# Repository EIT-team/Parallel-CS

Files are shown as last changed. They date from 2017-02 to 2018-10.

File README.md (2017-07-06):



# Parallel-CS
Parallel inject current source schematic and programming code, using AD9833 DDS IC.

Includes: Circuit schematics, PCB Layout, Arduino code for programming output frequency and/or phase of CS.

**Instructions for programming CS board**

- Turn on power (Press both push button switches).
- Connect mini-USB cable to Arduino.
- Open /src/DDS_PCB/DDS_PCB.ino and upload to Arduino.

Devices will be initially be programmed to default frequencies, specified in the src/frequencies.h file.

After programming, frequency and/or phase can be adjusted using serial monitor:
- Open serial monitor (Ctrl-Shift-M)
- Make sure line ending is set to '_no line ending_' and baud rate is 9600
- '_freq chan value_' will set the frequency of _chan_ to _value_ e.g. '_freq 2 2500_' sets channel 2 to 2500Hz
- '_phase chan value_' will set the phase in degrees of _chan_ to _value_ e.g. '_phase 2 50_' sets phase of channel 2 to 50 degrees. Phase is 0 by default.
- The terminal should echo a message confirming programming is happening.

Once programmed, the USB cable can be unplugged.

board

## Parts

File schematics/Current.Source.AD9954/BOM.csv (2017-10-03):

Qty | Value | Device | Package | Parts | Description | MF | MPN | OC_FARNELL | OC_NEWARK | PACKAGE | SUPPLIER | TP_SIGNAL_NAME
1 |  | JP3Q | JP3Q | JP1 | JUMPER
2 |  | M02-JST-2MM-SMT | JST-2-SMD | JP2, JP3 | Header 2
19 | 0.1uF | C-EUC0603 | C0603 | C1, C2, C4, C6, C7, C8, C9, C10, C11, C12, C13, C23, C25, C27, C29, C30, C31, C36, C38 | CAPACITOR, European symbol
4 | 100K | R-US_R0805 | R0805 | R1_0.1%, R2_0.1%, R6_0.1%, R7_0.1% | RESISTOR, American symbol
2 | 10k | R-US_R0805 | R0805 | R3, R_GAIN3_0.1% | RESISTOR, American symbol
17 | 10uF | C-EUC0603 | C0603 | C3, C5, C15, C16, C17, C18, C19, C20, C21, C24, C26, C28, C32, C33, C34, C35, C37 | CAPACITOR, European symbol
1 | 1150 | R-US_R0805 | R0805 | R4_DAC_1% | RESISTOR, American symbol
2 | 1500 | R-US_R0805 | R0805 | R2_DAC_1%, RG_DAC_1% | RESISTOR, American symbol
1 | 287 | R-US_R0805 | R0805 | RX_DAC_1% | RESISTOR, American symbol
1 | 2k | R-US_R0805 | R0805 | R_GAIN1_0.1% | RESISTOR, American symbol
1 | 309 | R-US_R0805 | R0805 | RY_DAC_1% | RESISTOR, American symbol
1 | 5k | R-US_R0805 | R0805 | R_GAIN2_0.1% | RESISTOR, American symbol
1 | 7.838k | R-US_R0805 | R0805 | R_SET1_0.1% | RESISTOR, American symbol
2 | 750 | R-US_R0805 | R0805 | R3_DAC_1%, RF_DAC_1% | RESISTOR, American symbol
1 | 931 | R-US_R0805 | R0805 | R1_DAC_1% | RESISTOR, American symbol
1 | AD9954YSVZ | AD9954YSVZ | QFP50P900X900X120-49N | U1 | Direct Digital Synthesizer |  | AD9954YSVZ | 1581969 | 19M8953 | TQFP-48 | ANALOG DEVICES
1 | ARDUINO_DUE | ARDUINO_DUE | ARDUINO_DUE | PCB1 | Device for representing an Arduino Due board with a footprint in an EAGLE design. Created by Dave Young for Element14. More EAGLE documentation at: http://www.element14.com/community/community/knode/cadsoft_eagle
1 | LTC1044CS8PBF | LTC1044CS8PBF | SOIC127P600X175-8N | U4 | Switched Capacitor Voltage Converter |  | LTC1044CS8#PBF | 1663593 | 55M8900 | SOIC-8 | Linear Technology
1 | LTC69000 | LTC69000 | SOT23-5L | U2 | Low Power, 1kHz to 20MHz
13 | PTR1PAD1-13 | PTR1PAD1-13 | P1-13 | 1.8VA, 1.8VD, 3V3, CLK, GND, IOUT+, IOUT-, SCLK, SDIO, SDO, TP5, VIN_NEG, VIN_POS | TEST PIN
1 | RC4560S08-RC4560 | RC4560S08-RC4560 | SO8 | OP1 | RC4560 Op-Amp
2 | REG1117 | REG1117 | SOT223 | IC1, IC2 | 800mA and 1A Low Dropout (LDO) Positive Regulator |  | REG1117 | 1097566 | 14P6981
1 | TL42PO | TL42PO | TL4XPO | S3 | TINY SWITCH ON - MOM

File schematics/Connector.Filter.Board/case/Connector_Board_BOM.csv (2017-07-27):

Part | Value | Device | Package | Description | BTM_NEG | BTM_POS | MF | MPN | OC_FARNELL | OC_NEWARK | PROD_ID | TOP_NEG | TOP_POS | TP_SIGNAL_NAME
C1 | 0.1uF | C-EUC0402 | C0402 | CAPACITOR, European symbol
C2 | 0.1uF | C-EUC0402 | C0402 | CAPACITOR, European symbol
C3 | 0.1uF | C-EUC0402 | C0402 | CAPACITOR, European symbol
C4 | 0.1uF | C-EUC0402 | C0402 | CAPACITOR, European symbol
C5 | 0.1uF | C-EUC0402 | C0402 | CAPACITOR, European symbol
C6 | 0.1uF | C-EUC0402 | C0402 | CAPACITOR, European symbol
C7 | 0.1uF | C-EUC0402 | C0402 | CAPACITOR, European symbol
C8 | 0.1uF | C-EUC0402 | C0402 | CAPACITOR, European symbol
C9 | 0.1uF | C-EUC0402 | C0402 | CAPACITOR, European symbol
C10 | 0.1uF | C-EUC0402 | C0402 | CAPACITOR, European symbol
C11 | 0.1uF | C-EUC0402 | C0402 | CAPACITOR, European symbol
C12 | 0.1uF | C-EUC0402 | C0402 | CAPACITOR, European symbol
C13 | 0.1uF | C-EUC0402 | C0402 | CAPACITOR, European symbol
C14 | 0.1uF | C-EUC0402 | C0402 | CAPACITOR, European symbol
C15 | 0.1uF | C-EUC0402 | C0402 | CAPACITOR, European symbol
C16 | 0.1uF | C-EUC0402 | C0402 | CAPACITOR, European symbol
C17 | 0.1uF | C-EUC0402 | C0402 | CAPACITOR, European symbol
C18 | 0.1uF | C-EUC0402 | C0402 | CAPACITOR, European symbol
C19 | 1uf | C-EUC0805 | C0805 | CAPACITOR, European symbol
C20 | 1uf | C-EUC0805 | C0805 | CAPACITOR, European symbol
C21 | 1uf | C-EUC0805 | C0805 | CAPACITOR, European symbol
C22 | 1uf | C-EUC0805 | C0805 | CAPACITOR, European symbol
C23 | 1uf | C-EUC0805 | C0805 | CAPACITOR, European symbol
C24 | 1uf | C-EUC0805 | C0805 | CAPACITOR, European symbol
C25 | 1uf | C-EUC0805 | C0805 | CAPACITOR, European symbol
C26 | 1uf | C-EUC0805 | C0805 | CAPACITOR, European symbol
C27 | 1uf | C-EUC0805 | C0805 | CAPACITOR, European symbol
C28 | 1uf | C-EUC0805 | C0805 | CAPACITOR, European symbol
C29 | 1uf | C-EUC0805 | C0805 | CAPACITOR, European symbol
C30 | 1uf | C-EUC0805 | C0805 | CAPACITOR, European symbol
C31 | 0.1uF | C-EUC0402 | C0402 | CAPACITOR, European symbol
C32 | 0.1uF | C-EUC0402 | C0402 | CAPACITOR, European symbol
C33 | 0.1uF | C-EUC0402 | C0402 | CAPACITOR, European symbol
C34 | 0.1uF | C-EUC0402 | C0402 | CAPACITOR, European symbol
C35 | 0.1uF | C-EUC0402 | C0402 | CAPACITOR, European symbol
C36 | 0.1uF | C-EUC0402 | C0402 | CAPACITOR, European symbol
C37 | 0.1uF | C-EUC0402 | C0402 | CAPACITOR, European symbol
C38 | 0.1uF | C-EUC0402 | C0402 | CAPACITOR, European symbol
C39 | 0.1uF | C-EUC0402 | C0402 | CAPACITOR, European symbol
C40 | 0.1uF | C-EUC0402 | C0402 | CAPACITOR, European symbol
C41 | 0.1uF | C-EUC0402 | C0402 | CAPACITOR, European symbol
C42 | 0.1uF | C-EUC0402 | C0402 | CAPACITOR, European symbol
C43 | 0.1uF | C-EUC0402 | C0402 | CAPACITOR, European symbol
C44 | 0.1uF | C-EUC0402 | C0402 | CAPACITOR, European symbol
C45 | 0.1uF | C-EUC0402 | C0402 | CAPACITOR, European symbol
C46 | 0.1uF | C-EUC0402 | C0402 | CAPACITOR, European symbol
C47 | 0.1uF | C-EUC0402 | C0402 | CAPACITOR, European symbol
C48 | 0.1uF | C-EUC0402 | C0402 | CAPACITOR, European symbol
C49 | 1uf | C-EUC0805 | C0805 | CAPACITOR, European symbol
C50 | 1uf | C-EUC0805 | C0805 | CAPACITOR, European symbol
C51 | 1uf | C-EUC0805 | C0805 | CAPACITOR, European symbol
C52 | 1uf | C-EUC0805 | C0805 | CAPACITOR, European symbol
C53 | 1uf | C-EUC0805 | C0805 | CAPACITOR, European symbol
C54 | 1uf | C-EUC0805 | C0805 | CAPACITOR, European symbol
C55 | 1uf | C-EUC0805 | C0805 | CAPACITOR, European symbol
C56 | 1uf | C-EUC0805 | C0805 | CAPACITOR, European symbol
C57 | 1uf | C-EUC0805 | C0805 | CAPACITOR, European symbol
C58 | 1uf | C-EUC0805 | C0805 | CAPACITOR, European symbol
C59 | 1uf | C-EUC0805 | C0805 | CAPACITOR, European symbol
C60 | 1uf | C-EUC0805 | C0805 | CAPACITOR, European symbol
C61 | 0.1uF | C-EUC0402 | C0402 | CAPACITOR, European symbol
C62 | 0.1uF | C-EUC0402 | C0402 | CAPACITOR, European symbol
C63 | 0.1uF | C-EUC0402 | C0402 | CAPACITOR, European symbol
C64 | 0.1uF | C-EUC0402 | C0402 | CAPACITOR, European symbol
C65 | 0.1uF | C-EUC0402 | C0402 | CAPACITOR, European symbol
C66 | 0.1uF | C-EUC0402 | C0402 | CAPACITOR, European symbol
C67 | 0.1uF | C-EUC0402 | C0402 | CAPACITOR, European symbol
C68 | 0.1uF | C-EUC0402 | C0402 | CAPACITOR, European symbol
C69 | 0.1uF | C-EUC0402 | C0402 | CAPACITOR, European symbol
C70 | 0.1uF | C-EUC0402 | C0402 | CAPACITOR, European symbol
C71 | 0.1uF | C-EUC0402 | C0402 | CAPACITOR, European symbol
C72 | 0.1uF | C-EUC0402 | C0402 | CAPACITOR, European symbol
C73 | 1uf | C-EUC0805 | C0805 | CAPACITOR, European symbol
C74 | 1uf | C-EUC0805 | C0805 | CAPACITOR, European symbol
C75 | 1uf | C-EUC0805 | C0805 | CAPACITOR, European symbol
C76 | 1uf | C-EUC0805 | C0805 | CAPACITOR, European symbol
C77 | 1uf | C-EUC0805 | C0805 | CAPACITOR, European symbol
C78 | 1uf | C-EUC0805 | C0805 | CAPACITOR, European symbol
C79 | 1uf | C-EUC0805 | C0805 | CAPACITOR, European symbol
C80 | 1uf | C-EUC0805 | C0805 | CAPACITOR, European symbol
C81 | 2.2uF | C-EUC0805 | C0805 | CAPACITOR, European symbol
C82 | 2.2uF | C-EUC0805 | C0805 | CAPACITOR, European symbol
C83 | 0.1uF | C-EUC0402 | C0402 | CAPACITOR, European symbol
C84 | 0.1uF | C-EUC0402 | C0402 | CAPACITOR, European symbol
C85 | 10nF | C-EUC0402 | C0402 | CAPACITOR, European symbol
C86 | 10nF | C-EUC0402 | C0402 | CAPACITOR, European symbol
D1 | 1N4148W-7-F | DIODE-SOD123 | SOD123 | DIODE
D2 | 1N4148W-7-F | DIODE-SOD123 | SOD123 | DIODE
J1 |  | JST_2MM_MALE | JST-2-SMD | Mates to single-cell LiPo batteries. | - | + |  |  |  |  | CONN-11443 | - | +
J2 |  | JST_2MM_MALE | JST-2-SMD | Mates to single-cell LiPo batteries. | - | + |  |  |  |  | CONN-11443 | - | +
JP1 |  | PINHD-1X2 | 1X02 | PIN HEADER
JP2 |  | PINHD-1X2 | 1X02 | PIN HEADER
JP3 |  | PINHD-2X2 | 2X02 | PIN HEADER
JP4 |  | PINHD-2X2 | 2X02 | PIN HEADER
LED1 |  | LEDSML0805 | SML0805 | LED
LED2 |  | LEDSML0805 | SML0805 | LED
R1 | 1M | R-EU_R0402 | R0402 | RESISTOR, European symbol
R2 | 1M | R-EU_R0402 | R0402 | RESISTOR, European symbol
R3 | 1M | R-EU_R0402 | R0402 | RESISTOR, European symbol
R4 | 1M | R-EU_R0402 | R0402 | RESISTOR, European symbol
R5 | 1M | R-EU_R0402 | R0402 | RESISTOR, European symbol
R6 | 1M | R-EU_R0402 | R0402 | RESISTOR, European symbol
R7 | 1M | R-EU_R0402 | R0402 | RESISTOR, European symbol
R8 | 1M | R-EU_R0402 | R0402 | RESISTOR, European symbol
R9 | 1M | R-EU_R0402 | R0402 | RESISTOR, European symbol
R10 | 1M | R-EU_R0402 | R0402 | RESISTOR, European symbol
R11 | 1M | R-EU_R0402 | R0402 | RESISTOR, European symbol
R12 | 1M | R-EU_R0402 | R0402 | RESISTOR, European symbol
R13 | 1M | R-EU_R0402 | R0402 | RESISTOR, European symbol
R14 | 1M | R-EU_R0402 | R0402 | RESISTOR, European symbol
R15 | 1M | R-EU_R0402 | R0402 | RESISTOR, European symbol
R16 | 1M | R-EU_R0402 | R0402 | RESISTOR, European symbol
R17 | 1M | R-EU_R0402 | R0402 | RESISTOR, European symbol
R18 | 1M | R-EU_R0402 | R0402 | RESISTOR, European symbol
R19 | 1M | R-EU_R0402 | R0402 | RESISTOR, European symbol
R20 | 1M | R-EU_R0402 | R0402 | RESISTOR, European symbol
R21 | 1M | R-EU_R0402 | R0402 | RESISTOR, European symbol
R22 | 1M | R-EU_R0402 | R0402 | RESISTOR, European symbol
R23 | 1M | R-EU_R0402 | R0402 | RESISTOR, European symbol
R24 | 1M | R-EU_R0402 | R0402 | RESISTOR, European symbol
R25 | 1M | R-EU_R0402 | R0402 | RESISTOR, European symbol
R26 | 1M | R-EU_R0402 | R0402 | RESISTOR, European symbol
R27 | 1M | R-EU_R0402 | R0402 | RESISTOR, European symbol
R28 | 1M | R-EU_R0402 | R0402 | RESISTOR, European symbol
R29 | 1M | R-EU_R0402 | R0402 | RESISTOR, European symbol
R30 | 1M | R-EU_R0402 | R0402 | RESISTOR, European symbol
R31 | 1M | R-EU_R0402 | R0402 | RESISTOR, European symbol
R32 | 1M | R-EU_R0402 | R0402 | RESISTOR, European symbol
R33 | 1.6M | R-EU_R0805 | R0805 | RESISTOR, European symbol
R34 | 1.6M | R-EU_R0805 | R0805 | RESISTOR, European symbol
R35 | 1.6M | R-EU_R0805 | R0805 | RESISTOR, European symbol
R36 | 1.6M | R-EU_R0805 | R0805 | RESISTOR, European symbol
R37 | 1.6M | R-EU_R0805 | R0805 | RESISTOR, European symbol
R38 | 1.6M | R-EU_R0805 | R0805 | RESISTOR, European symbol
R39 | 1.6M | R-EU_R0805 | R0805 | RESISTOR, European symbol
R40 | 1.6M | R-EU_R0805 | R0805 | RESISTOR, European symbol
R41 | 1.6M | R-EU_R0805 | R0805 | RESISTOR, European symbol
R42 | 1.6M | R-EU_R0805 | R0805 | RESISTOR, European symbol
R43 | 1.6M | R-EU_R0805 | R0805 | RESISTOR, European symbol
R44 | 1.6M | R-EU_R0805 | R0805 | RESISTOR, European symbol
R45 | 1.6M | R-EU_R0805 | R0805 | RESISTOR, European symbol
R46 | 1.6M | R-EU_R0805 | R0805 | RESISTOR, European symbol
R47 | 1.6M | R-EU_R0805 | R0805 | RESISTOR, European symbol
R48 | 1.6M | R-EU_R0805 | R0805 | RESISTOR, European symbol
R49 | 1.6M | R-EU_R0805 | R0805 | RESISTOR, European symbol
R50 | 1.6M | R-EU_R0805 | R0805 | RESISTOR, European symbol
R51 | 1.6M | R-EU_R0805 | R0805 | RESISTOR, European symbol
R52 | 1.6M | R-EU_R0805 | R0805 | RESISTOR, European symbol
R53 | 1.6M | R-EU_R0805 | R0805 | RESISTOR, European symbol
R54 | 1.6M | R-EU_R0805 | R0805 | RESISTOR, European symbol
R55 | 1.6M | R-EU_R0805 | R0805 | RESISTOR, European symbol
R56 | 1.6M | R-EU_R0805 | R0805 | RESISTOR, European symbol
R57 | 1.6M | R-EU_R0805 | R0805 | RESISTOR, European symbol
R58 | 1.6M | R-EU_R0805 | R0805 | RESISTOR, European symbol
R59 | 1.6M | R-EU_R0805 | R0805 | RESISTOR, European symbol
R60 | 1.6M | R-EU_R0805 | R0805 | RESISTOR, European symbol
R61 | 1.6M | R-EU_R0805 | R0805 | RESISTOR, European symbol
R62 | 1.6M | R-EU_R0805 | R0805 | RESISTOR, European symbol
R63 | 1.6M | R-EU_R0805 | R0805 | RESISTOR, European symbol
R64 | 1.6M | R-EU_R0805 | R0805 | RESISTOR, European symbol
R65 | 1k | R-EU_R0402 | R0402 | RESISTOR, European symbol
R66 | 1k | R-EU_R0402 | R0402 | RESISTOR, European symbol
TP1 | TOUCHPROOF | TOUCHPROOF | TOUCHPROOF_PIN | Description Big hole for touch proof pins
TP2 | TOUCHPROOF | TOUCHPROOF | TOUCHPROOF_PIN | Description Big hole for touch proof pins
TP3 | TOUCHPROOF | TOUCHPROOF | TOUCHPROOF_PIN | Description Big hole for touch proof pins
TP4 | TOUCHPROOF | TOUCHPROOF | TOUCHPROOF_PIN | Description Big hole for touch proof pins
TP5 | TOUCHPROOF | TOUCHPROOF | TOUCHPROOF_PIN | Description Big hole for touch proof pins
TP6 | TOUCHPROOF | TOUCHPROOF | TOUCHPROOF_PIN | Description Big hole for touch proof pins
TP7 | TOUCHPROOF | TOUCHPROOF | TOUCHPROOF_PIN | Description Big hole for touch proof pins
TP8 | TOUCHPROOF | TOUCHPROOF | TOUCHPROOF_PIN | Description Big hole for touch proof pins
TP9 | TOUCHPROOF | TOUCHPROOF | TOUCHPROOF_PIN | Description Big hole for touch proof pins
TP10 | TOUCHPROOF | TOUCHPROOF | TOUCHPROOF_PIN | Description Big hole for touch proof pins
TP11 | TOUCHPROOF | TOUCHPROOF | TOUCHPROOF_PIN | Description Big hole for touch proof pins
TP12 | TOUCHPROOF | TOUCHPROOF | TOUCHPROOF_PIN | Description Big hole for touch proof pins
TP13 | TOUCHPROOF | TOUCHPROOF | TOUCHPROOF_PIN | Description Big hole for touch proof pins
TP14 | TOUCHPROOF | TOUCHPROOF | TOUCHPROOF_PIN | Description Big hole for touch proof pins
TP15 | TOUCHPROOF | TOUCHPROOF | TOUCHPROOF_PIN | Description Big hole for touch proof pins
TP16 | TOUCHPROOF | TOUCHPROOF | TOUCHPROOF_PIN | Description Big hole for touch proof pins
TP17 | TOUCHPROOF | TOUCHPROOF | TOUCHPROOF_PIN | Description Big hole for touch proof pins
TP18 | TOUCHPROOF | TOUCHPROOF | TOUCHPROOF_PIN | Description Big hole for touch proof pins
TP19 | TOUCHPROOF | TOUCHPROOF | TOUCHPROOF_PIN | Description Big hole for touch proof pins
TP20 | TOUCHPROOF | TOUCHPROOF | TOUCHPROOF_PIN | Description Big hole for touch proof pins
TP21 | TOUCHPROOF | TOUCHPROOF | TOUCHPROOF_PIN | Description Big hole for touch proof pins
TP22 | TOUCHPROOF | TOUCHPROOF | TOUCHPROOF_PIN | Description Big hole for touch proof pins
TP23 | TOUCHPROOF | TOUCHPROOF | TOUCHPROOF_PIN | Description Big hole for touch proof pins
TP24 | TOUCHPROOF | TOUCHPROOF | TOUCHPROOF_PIN | Description Big hole for touch proof pins
TP25 | TOUCHPROOF | TOUCHPROOF | TOUCHPROOF_PIN | Description Big hole for touch proof pins
TP26 | TOUCHPROOF | TOUCHPROOF | TOUCHPROOF_PIN | Description Big hole for touch proof pins
TP27 | TOUCHPROOF | TOUCHPROOF | TOUCHPROOF_PIN | Description Big hole for touch proof pins
TP28 | TOUCHPROOF | TOUCHPROOF | TOUCHPROOF_PIN | Description Big hole for touch proof pins
TP29 | TOUCHPROOF | TOUCHPROOF | TOUCHPROOF_PIN | Description Big hole for touch proof pins
TP30 | TOUCHPROOF | TOUCHPROOF | TOUCHPROOF_PIN | Description Big hole for touch proof pins
TP31 | TOUCHPROOF | TOUCHPROOF | TOUCHPROOF_PIN | Description Big hole for touch proof pins
TP32 | TOUCHPROOF | TOUCHPROOF | TOUCHPROOF_PIN | Description Big hole for touch proof pins
U1 | AD8244 | AD8244 | MSOP10
U2 | AD8244 | AD8244 | MSOP10
U3 | AD8244 | AD8244 | MSOP10
U4 | AD8244 | AD8244 | MSOP10
U5 | AD8244 | AD8244 | MSOP10
U6 | AD8244 | AD8244 | MSOP10
U7 | AD8244 | AD8244 | MSOP10
U8 | AD8244 | AD8244 | MSOP10
U9 | AD8244 | AD8244 | MSOP10
U10 | AD8244 | AD8244 | MSOP10
U11 | AD8244 | AD8244 | MSOP10
U12 | AD8244 | AD8244 | MSOP10
U13 | AD8244 | AD8244 | MSOP10
U14 | AD8244 | AD8244 | MSOP10
U15 | AD8244 | AD8244 | MSOP10
U16 | AD8244 | AD8244 | MSOP10
U17 | AD8244 | AD8244 | MSOP10
U18 | AD8244 | AD8244 | MSOP10
U19 | AD8244 | AD8244 | MSOP10
U20 | AD8244 | AD8244 | MSOP10
U21 | AD8244 | AD8244 | MSOP10
U22 | AD8244 | AD8244 | MSOP10
U23 | AD8244 | AD8244 | MSOP10
U24 | AD8244 | AD8244 | MSOP10
X1 | EEGCON | M37HP | M37HP | SUB-D |  |  |  |  | unknown | unknown
X2 | EITCON | F37HP | F37HP | SUB-D |  |  |  |  | unknown | unknown

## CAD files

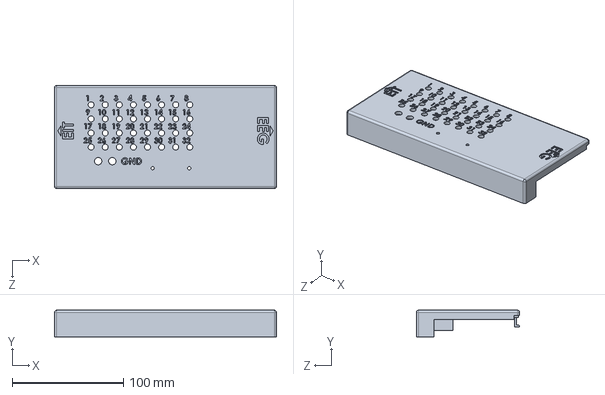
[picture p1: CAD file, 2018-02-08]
schematics/Connector.Filter.Board/case/filter_board_case-top.SLDPRT
200.0 x 24.0 x 93.0 mm

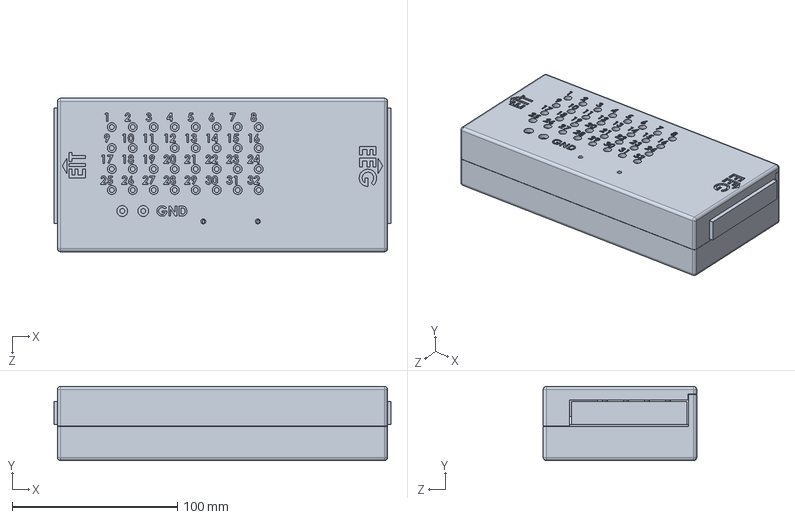
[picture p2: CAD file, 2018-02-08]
schematics/Connector.Filter.Board/case/filter_board_case.SLDPRT
204.0 x 45.0 x 93.0 mm

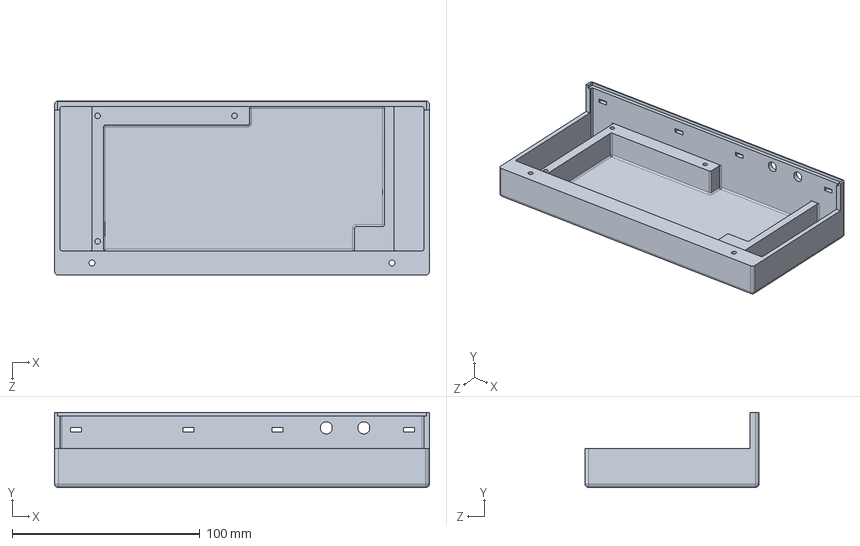
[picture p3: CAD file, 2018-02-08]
schematics/Connector.Filter.Board/case/filter_board_case-Bottom.SLDPRT
200.0 x 40.0 x 93.0 mm

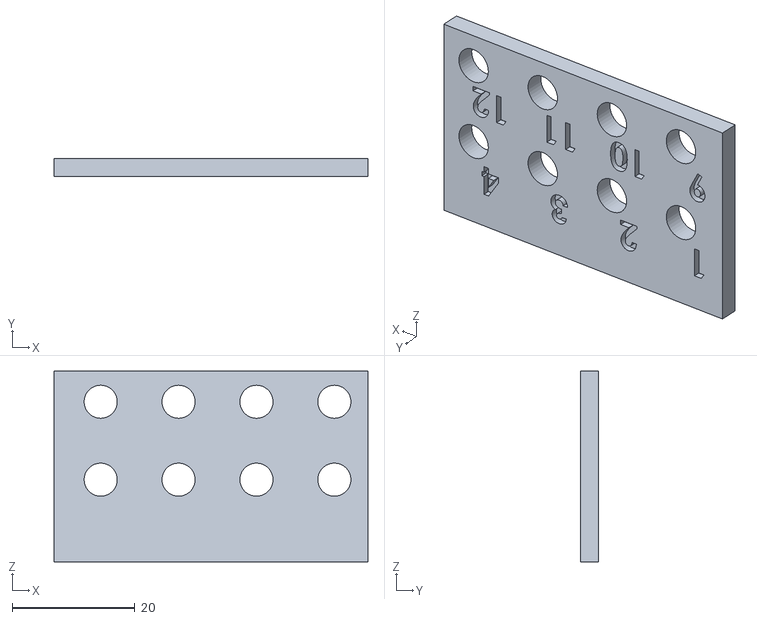
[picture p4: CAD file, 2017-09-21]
schematics/Connector.Filter.Board/case/holes.STL
51.2 x 3.00 x 31.1

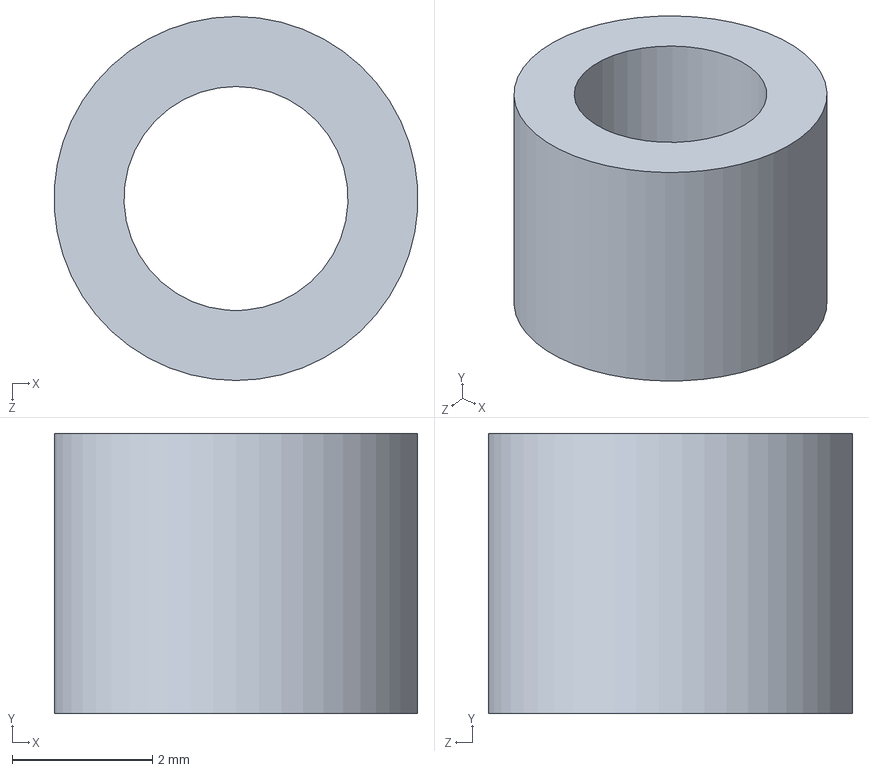
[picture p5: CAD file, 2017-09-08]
schematics/Connector.Filter.Board/case/Part2.SLDPRT
5.19 x 4.00 x 5.20 mm

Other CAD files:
schematics/Connector.Filter.Board/case/filter_board_case-Bottom.STL
schematics/Connector.Filter.Board/case/filter_board_case-top.STL

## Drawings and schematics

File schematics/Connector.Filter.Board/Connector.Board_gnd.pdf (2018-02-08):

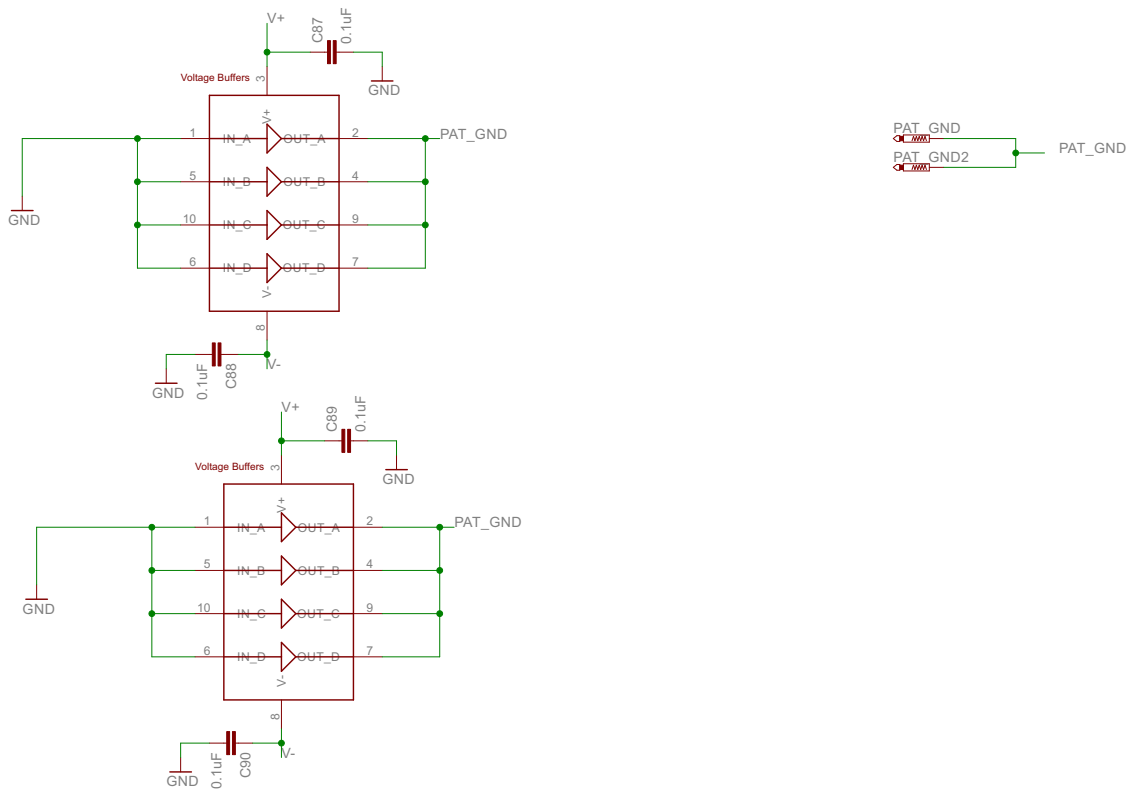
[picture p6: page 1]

0.1uF GND 0.1uF GND GND 0.1uF GND 0.1uF GND GND IN_A 1 OUT_A 2 V+ 3 OUT_B 4 IN_B 5 IN_D 6 OUT_D 7 V- 8 OUT_C 9 IN_C 10 C87 C88 PAT_GND PAT_GND2 IN_A 1 OUT_A 2 V+ 3 OUT_B 4 IN_B 5 IN_D 6 OUT_D 7 V- 8 OUT_C 9 IN_C 10 C89 C90 V+V+ V-V- PAT_GND PAT_GND PAT_GND Voltage Buffers Voltage Buffers

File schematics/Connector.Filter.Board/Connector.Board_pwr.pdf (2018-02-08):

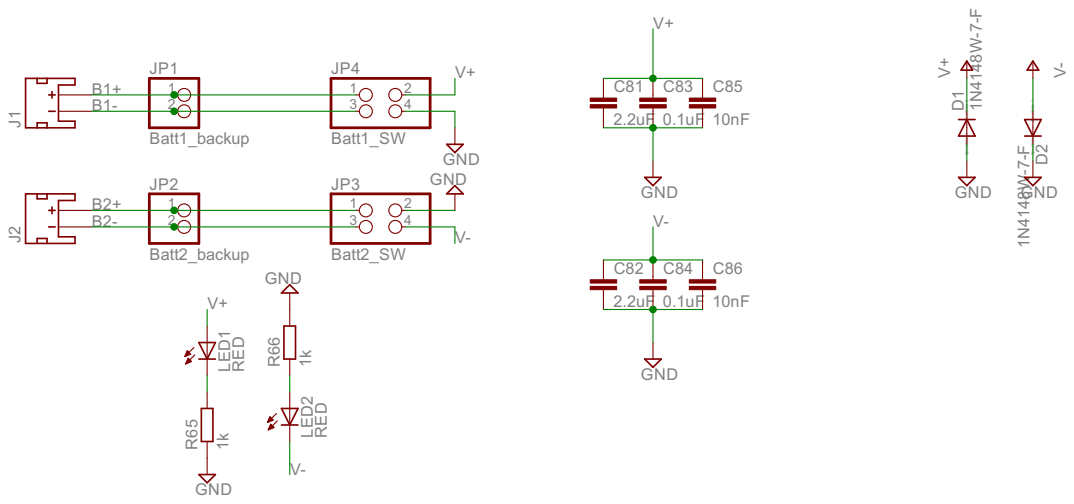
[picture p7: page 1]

SpiceOrder 1 SpiceOrder 2 SpiceOrder 1 SpiceOrder 2 Batt1_backup Batt2_backup GNDGND 0.1uF 0.1uF GND GND 1N4148W-7-F 1N4148W-7-F V+V- GND GND 2.2uF 10nF 2.2uF 10nF Batt1_SW Batt2_SW RED RED 1k GND 1k GND JP112 JP212 C83 C84 D1 D2 C81 C85 C82 C86 J1 J2 JP41 2 3 4 JP31 2 3 4 LED1 LED2 R65 R66 V- V- V- V+ V+ V+ B1+ B1- B2+ B2-

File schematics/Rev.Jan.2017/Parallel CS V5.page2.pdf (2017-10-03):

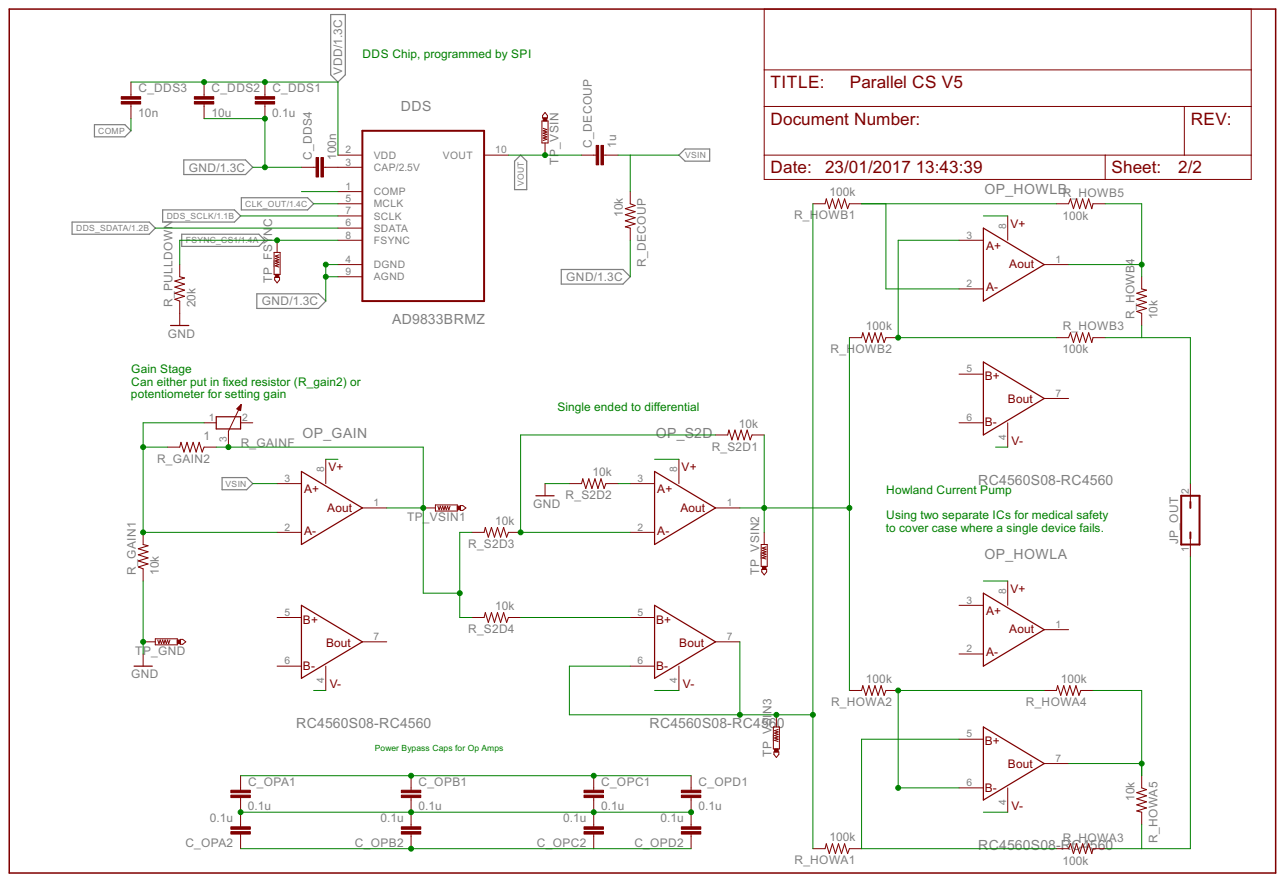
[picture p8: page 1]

DDS Chip, programmed by SPI

Using two separate ICs for medical safety
to cover case where a single device fails.

Power Bypass Caps for Op Amps

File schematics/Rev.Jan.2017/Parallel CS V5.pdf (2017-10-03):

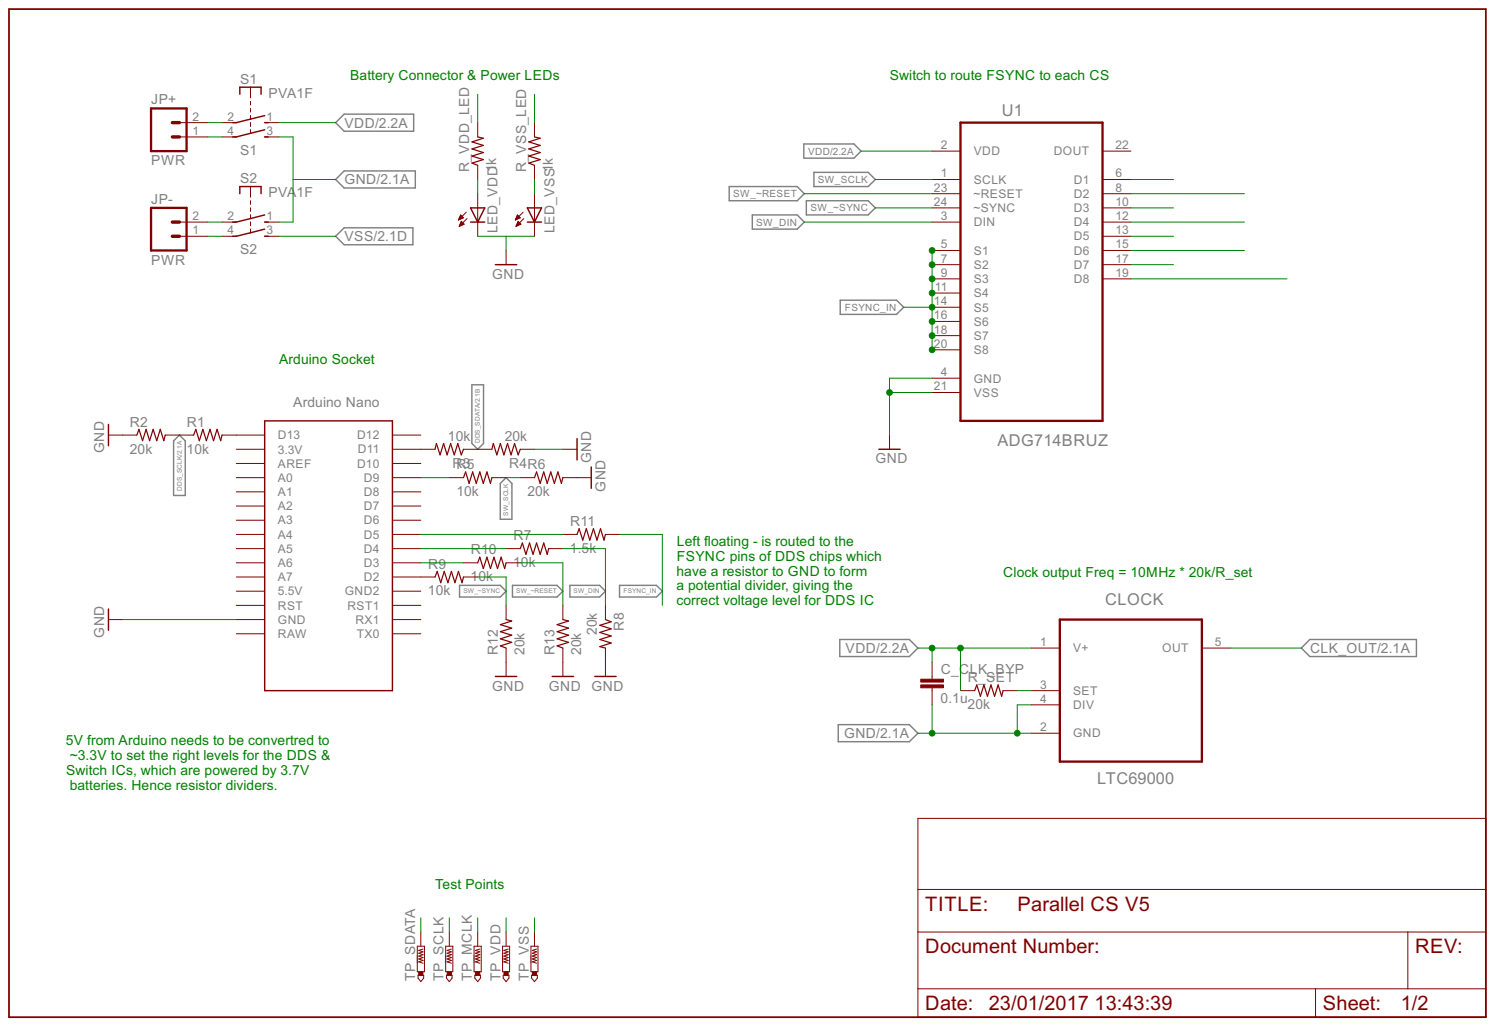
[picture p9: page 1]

Battery Connector & Power LEDs

Switch to route FSYNC to each CS

Left floating - is routed to the FSYNC pins of DDS chips which

have a resistor to GND to form
a potential divider, giving the
correct voltage level for DDS IC

5V from Arduino needs to be convertred to ~3.3V to set the right levels for the DDS &

Switch ICs, which are powered by 3.7V
batteries. Hence resistor dividers.

Document Number: | REV:

Date: 23/01/2017 13:43:39 | Sheet: 1/2

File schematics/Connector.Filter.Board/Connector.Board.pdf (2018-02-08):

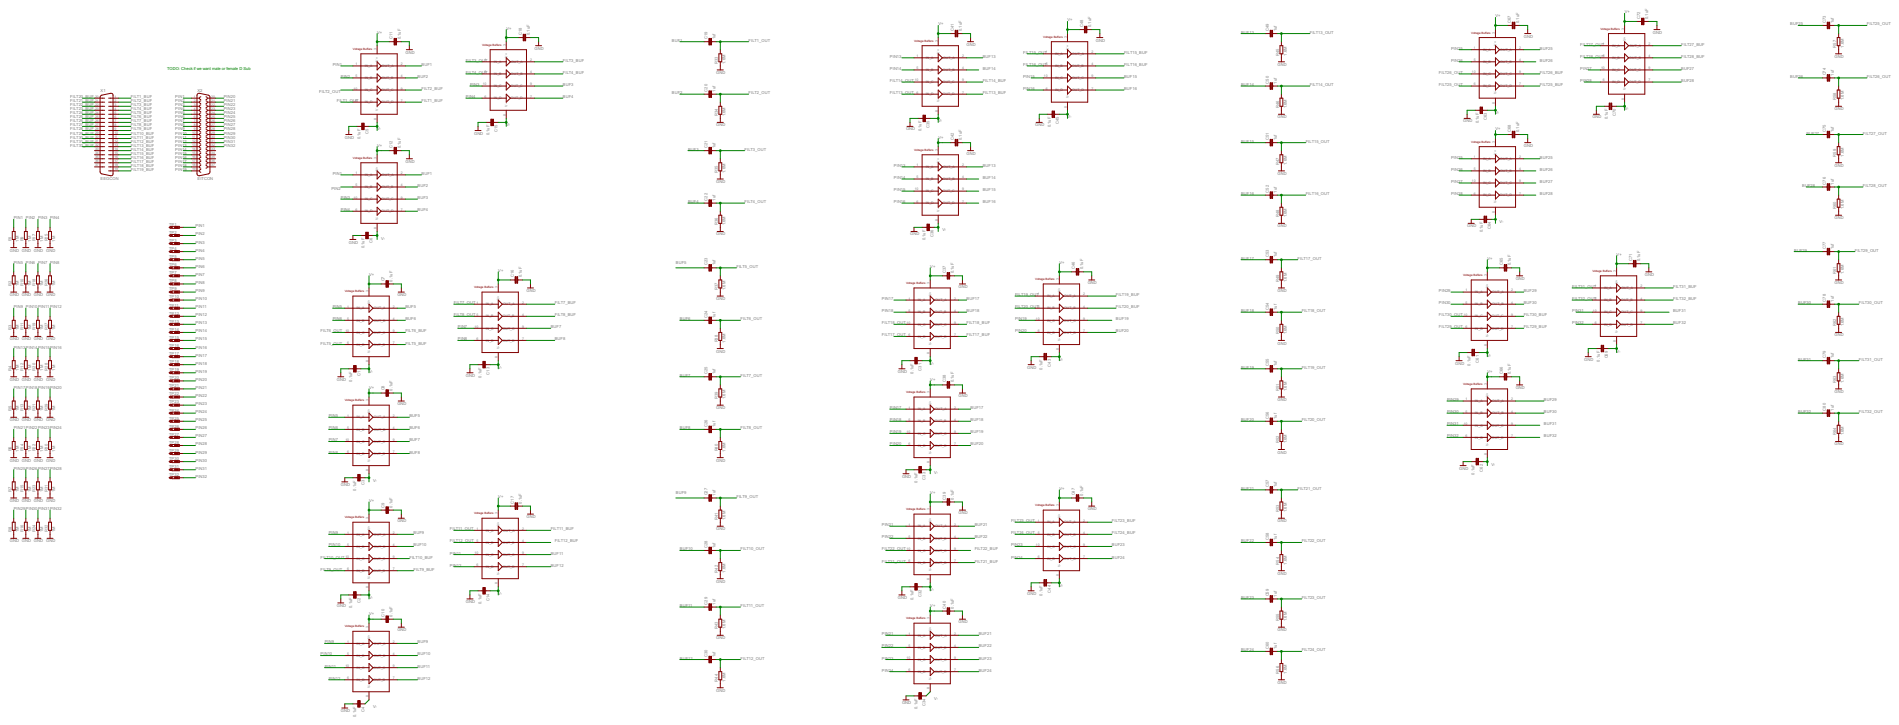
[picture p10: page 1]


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

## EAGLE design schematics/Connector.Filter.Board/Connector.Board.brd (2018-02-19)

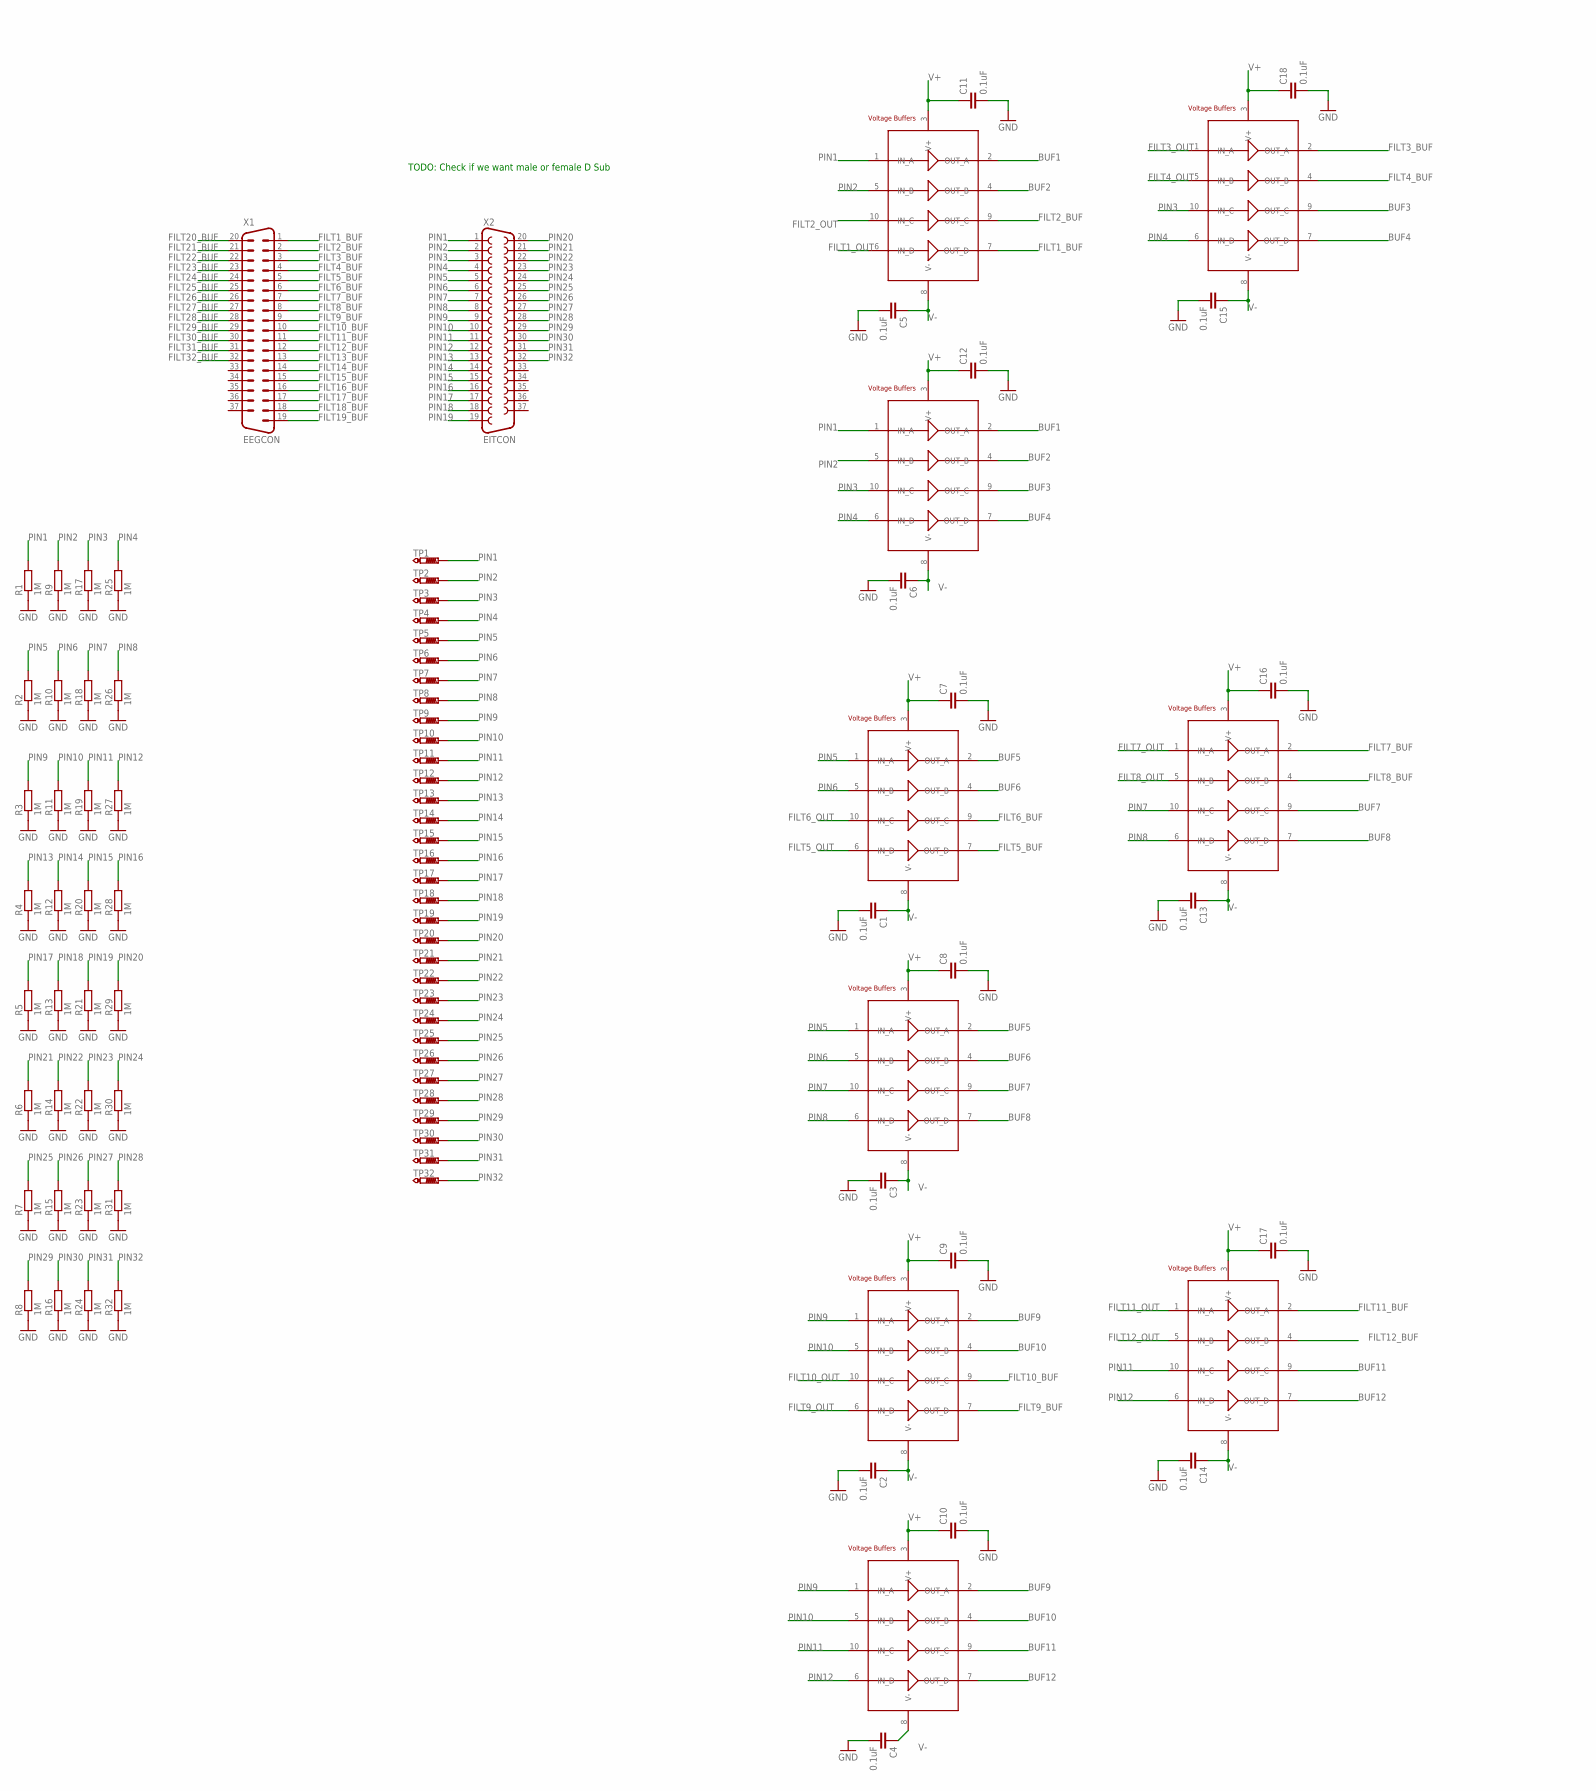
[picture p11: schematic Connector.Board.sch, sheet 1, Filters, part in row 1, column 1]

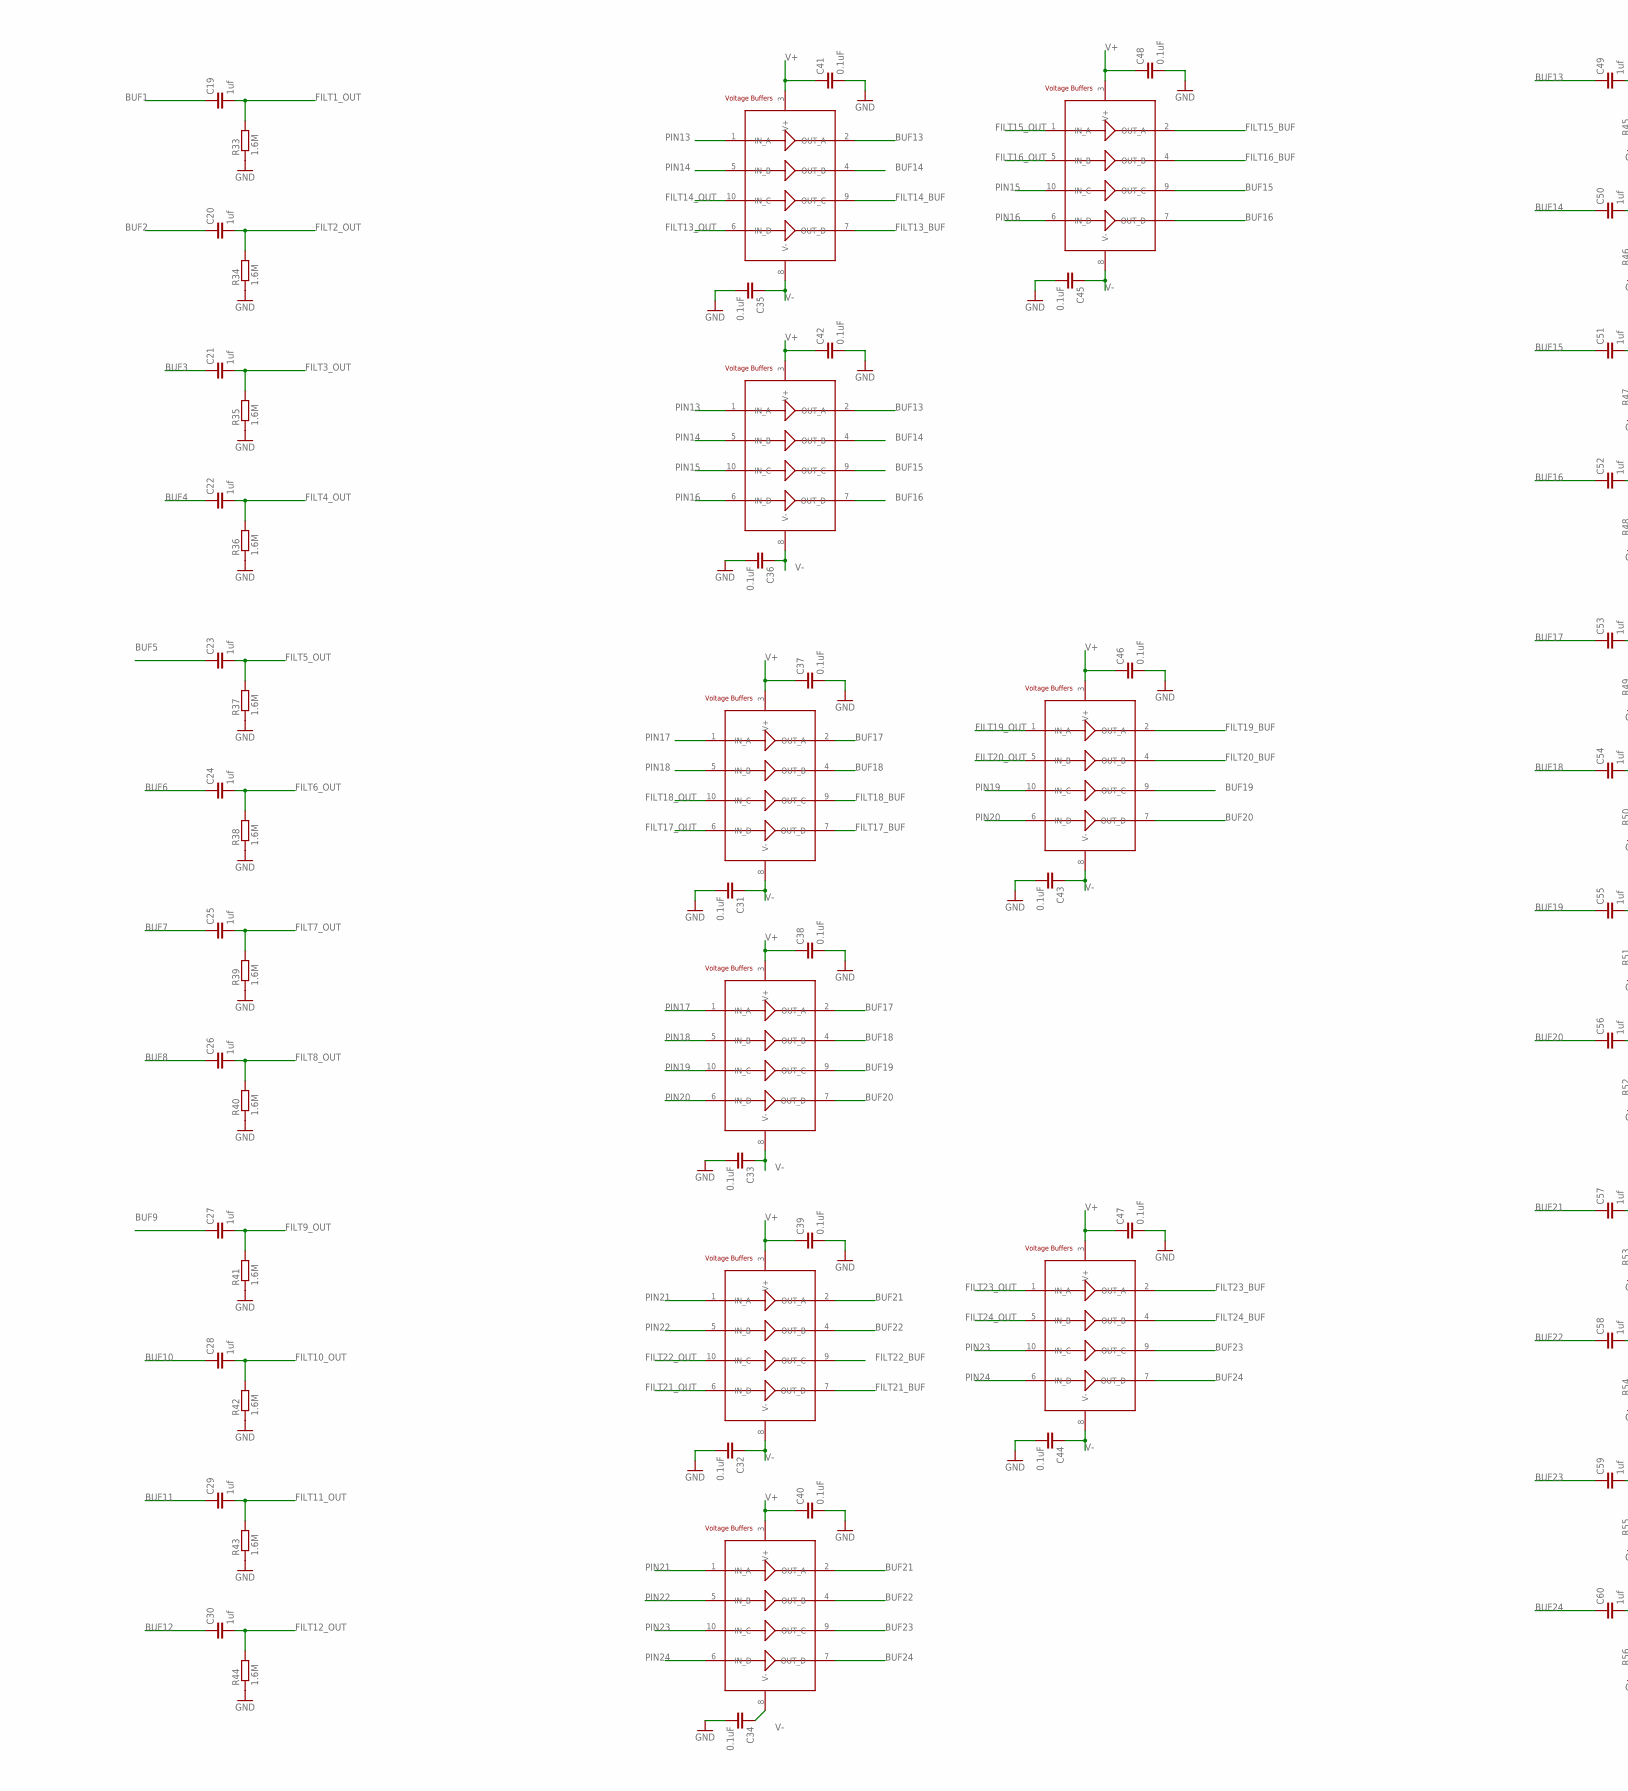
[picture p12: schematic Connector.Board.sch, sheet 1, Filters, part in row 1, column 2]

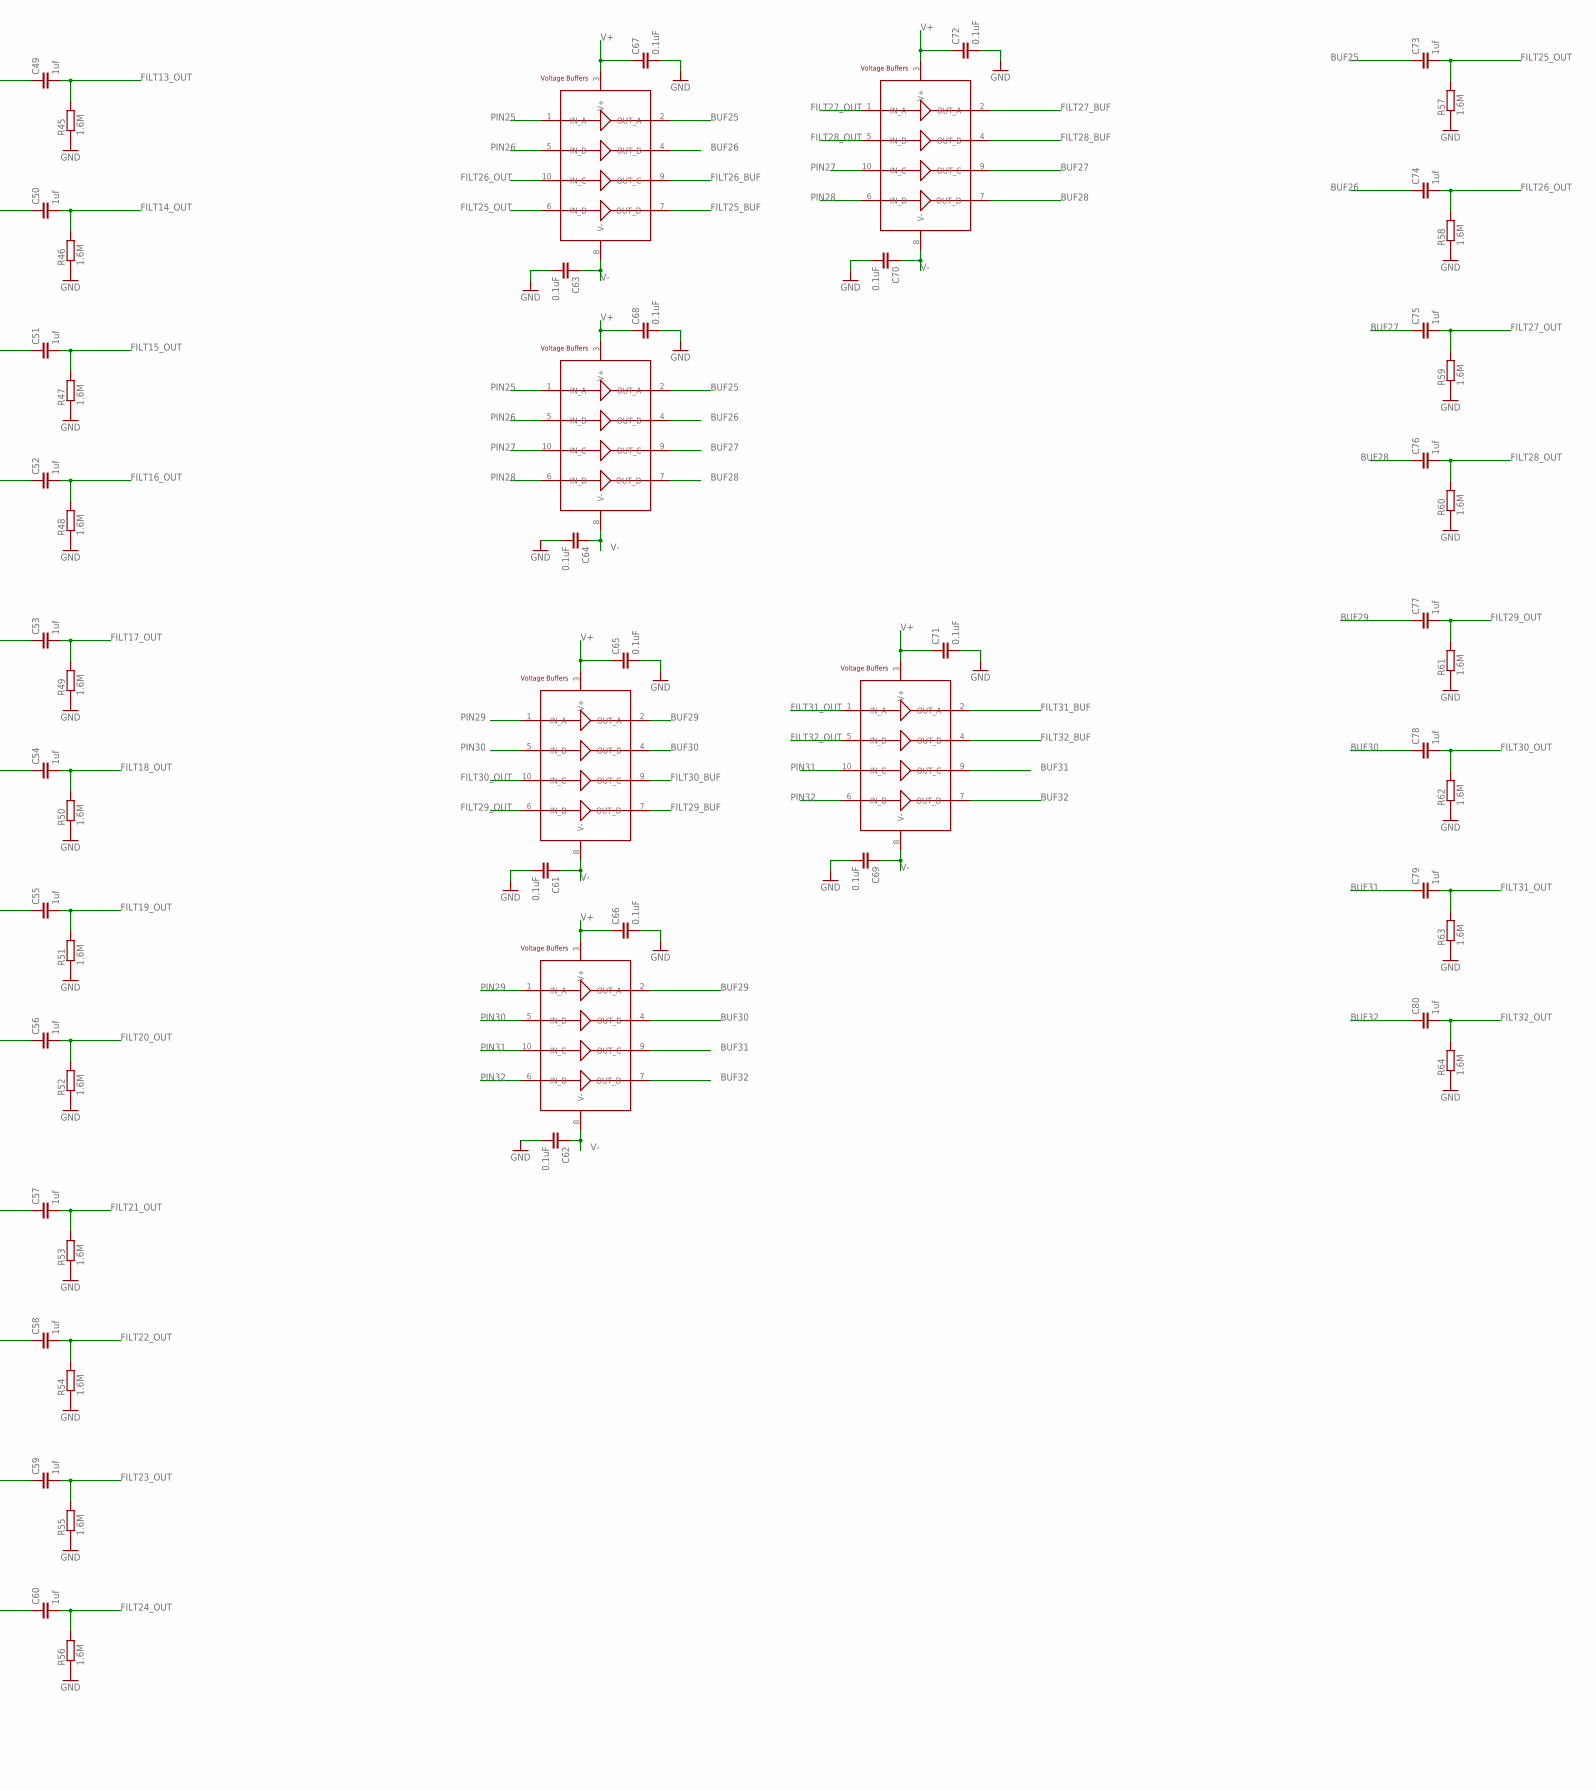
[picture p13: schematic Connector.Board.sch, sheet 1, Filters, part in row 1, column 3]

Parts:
C1, C2, C3, C4, C5, C6, C7, C8, C9, C10, C11, C12, C13, C14, C15, C16, C17, C18, C31, C32, C33, C34, C35, C36, C37, C38, C39, C40, C41, C42, C43, C44, C45, C46, C47, C48, C61, C62, C63, C64, C65, C66, C67, C68, C69, C70, C71, C72: 0.1uF; C0402
C19, C20, C21, C22, C23, C24, C25, C26, C27, C28, C29, C30, C49, C50, C51, C52, C53, C54, C55, C56, C57, C58, C59, C60, C73, C74, C75, C76, C77, C78, C79, C80: 1uf; C0805
R1, R2, R3, R4, R5, R6, R7, R8, R9, R10, R11, R12, R13, R14, R15, R16, R17, R18, R19, R20, R21, R22, R23, R24, R25, R26, R27, R28, R29, R30, R31, R32: 1M; R0402
R33, R34, R35, R36, R37, R38, R39, R40, R41, R42, R43, R44, R45, R46, R47, R48, R49, R50, R51, R52, R53, R54, R55, R56, R57, R58, R59, R60, R61, R62, R63, R64: 1.6M; R0805
TP1, TP2, TP3, TP4, TP5, TP6, TP7, TP8, TP9, TP10, TP11, TP12, TP13, TP14, TP15, TP16, TP17, TP18, TP19, TP20, TP21, TP22, TP23, TP24, TP25, TP26, TP27, TP28, TP29, TP30, TP31, TP32: TOUCHPROOF; TOUCHPROOF_PIN
U1, U2, U3, U4, U5, U6, U7, U8, U9, U10, U11, U12, U13, U14, U15, U16, U17, U18, U19, U20, U21, U22, U23, U24: AD8244; MSOP10
X1: EEGCON; M37HP
X2: EITCON; F37HP

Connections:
BUF1: C19.1, U5.2 (OUT_A), U6.2 (OUT_A)
BUF2: C20.1, U5.4 (OUT_B), U6.4 (OUT_B)
BUF3: C21.1, U6.9 (OUT_C), U9.9 (OUT_C)
BUF4: C22.1, U6.7 (OUT_D), U9.7 (OUT_D)
BUF5: C23.1, U1.2 (OUT_A), U2.2 (OUT_A)
BUF6: C24.1, U1.4 (OUT_B), U2.4 (OUT_B)
BUF7: C25.1, U2.9 (OUT_C), U7.9 (OUT_C)
BUF8: C26.1, U2.7 (OUT_D), U7.7 (OUT_D)
BUF9: C27.1, U3.2 (OUT_A), U4.2 (OUT_A)
BUF10: C28.1, U3.4 (OUT_B), U4.4 (OUT_B)
BUF11: C29.1, U4.9 (OUT_C), U8.9 (OUT_C)
BUF12: C30.1, U4.7 (OUT_D), U8.7 (OUT_D)
BUF13: C49.1, U14.2 (OUT_A), U15.2 (OUT_A)
BUF14: C50.1, U14.4 (OUT_B), U15.4 (OUT_B)
BUF15: C51.1, U15.9 (OUT_C), U18.9 (OUT_C)
BUF16: C52.1, U15.7 (OUT_D), U18.7 (OUT_D)
BUF17: C53.1, U10.2 (OUT_A), U11.2 (OUT_A)
BUF18: C54.1, U10.4 (OUT_B), U11.4 (OUT_B)
BUF19: C55.1, U11.9 (OUT_C), U16.9 (OUT_C)
BUF20: C56.1, U11.7 (OUT_D), U16.7 (OUT_D)
BUF21: C57.1, U12.2 (OUT_A), U13.2 (OUT_A)
BUF22: C58.1, U12.4 (OUT_B), U13.4 (OUT_B)
BUF23: C59.1, U13.9 (OUT_C), U17.9 (OUT_C)
BUF24: C60.1, U13.7 (OUT_D), U17.7 (OUT_D)
BUF25: C73.1, U21.2 (OUT_A), U22.2 (OUT_A)
BUF26: C74.1, U21.4 (OUT_B), U22.4 (OUT_B)
BUF27: C75.1, U22.9 (OUT_C), U24.9 (OUT_C)
BUF28: C76.1, U22.7 (OUT_D), U24.7 (OUT_D)
BUF29: C77.1, U19.2 (OUT_A), U20.2 (OUT_A)
BUF30: C78.1, U19.4 (OUT_B), U20.4 (OUT_B)
BUF31: C79.1, U20.9 (OUT_C), U23.9 (OUT_C)
BUF32: C80.1, U20.7 (OUT_D), U23.7 (OUT_D)
FILT1_BUF: U5.7 (OUT_D), X1.1
FILT1_OUT: C19.2, R33.2, U5.6 (IN_D)
FILT2_BUF: U5.9 (OUT_C), X1.2
FILT2_OUT: C20.2, R34.2, U5.10 (IN_C)
FILT3_BUF: U9.2 (OUT_A), X1.3
FILT3_OUT: C21.2, R35.2, U9.1 (IN_A)
FILT4_BUF: U9.4 (OUT_B), X1.4
FILT4_OUT: C22.2, R36.2, U9.5 (IN_B)
FILT5_BUF: U1.7 (OUT_D), X1.5
FILT5_OUT: C23.2, R37.2, U1.6 (IN_D)
FILT6_BUF: U1.9 (OUT_C), X1.6
FILT6_OUT: C24.2, R38.2, U1.10 (IN_C)
FILT7_BUF: U7.2 (OUT_A), X1.7
FILT7_OUT: C25.2, R39.2, U7.1 (IN_A)
FILT8_BUF: U7.4 (OUT_B), X1.8
FILT8_OUT: C26.2, R40.2, U7.5 (IN_B)
FILT9_BUF: U3.7 (OUT_D), X1.9
FILT9_OUT: C27.2, R41.2, U3.6 (IN_D)
FILT10_BUF: U3.9 (OUT_C), X1.10
FILT10_OUT: C28.2, R42.2, U3.10 (IN_C)
FILT11_BUF: U8.2 (OUT_A), X1.11
FILT11_OUT: C29.2, R43.2, U8.1 (IN_A)
FILT12_BUF: U8.4 (OUT_B), X1.12
FILT12_OUT: C30.2, R44.2, U8.5 (IN_B)
FILT13_BUF: U14.7 (OUT_D), X1.13
FILT13_OUT: C49.2, R45.2, U14.6 (IN_D)
FILT14_BUF: U14.9 (OUT_C), X1.14
FILT14_OUT: C50.2, R46.2, U14.10 (IN_C)
FILT15_BUF: U18.2 (OUT_A), X1.15
FILT15_OUT: C51.2, R47.2, U18.1 (IN_A)
FILT16_BUF: U18.4 (OUT_B), X1.16
FILT16_OUT: C52.2, R48.2, U18.5 (IN_B)
FILT17_BUF: U10.7 (OUT_D), X1.17
FILT17_OUT: C53.2, R49.2, U10.6 (IN_D)
FILT18_BUF: U10.9 (OUT_C), X1.18
FILT18_OUT: C54.2, R50.2, U10.10 (IN_C)
FILT19_BUF: U16.2 (OUT_A), X1.19
FILT19_OUT: C55.2, R51.2, U16.1 (IN_A)
FILT20_BUF: U16.4 (OUT_B), X1.20
FILT20_OUT: C56.2, R52.2, U16.5 (IN_B)
FILT21_BUF: U12.7 (OUT_D), X1.21
FILT21_OUT: C57.2, R53.2, U12.6 (IN_D)
FILT22_BUF: U12.9 (OUT_C), X1.22
FILT22_OUT: C58.2, R54.2, U12.10 (IN_C)
FILT23_BUF: U17.2 (OUT_A), X1.23
FILT23_OUT: C59.2, R55.2, U17.1 (IN_A)
FILT24_BUF: U17.4 (OUT_B), X1.24
FILT24_OUT: C60.2, R56.2, U17.5 (IN_B)
FILT25_BUF: U21.7 (OUT_D), X1.25
FILT25_OUT: C73.2, R57.2, U21.6 (IN_D)
FILT26_BUF: U21.9 (OUT_C), X1.26
FILT26_OUT: C74.2, R58.2, U21.10 (IN_C)
FILT27_BUF: U24.2 (OUT_A), X1.27
FILT27_OUT: C75.2, R59.2, U24.1 (IN_A)
FILT28_BUF: U24.4 (OUT_B), X1.28
FILT28_OUT: C76.2, R60.2, U24.5 (IN_B)
FILT29_BUF: U19.7 (OUT_D), X1.29
FILT29_OUT: C77.2, R61.2, U19.6 (IN_D)
FILT30_BUF: U19.9 (OUT_C), X1.30
FILT30_OUT: C78.2, R62.2, U19.10 (IN_C)
FILT31_BUF: U23.2 (OUT_A), X1.31
FILT31_OUT: C79.2, R63.2, U23.1 (IN_A)
FILT32_BUF: U23.4 (OUT_B), X1.32
FILT32_OUT: C80.2, R64.2, U23.5 (IN_B)
GND: C1.2, C2.2, C3.2, C4.2, C5.2, C6.2, C7.2, C8.2, C9.2, C10.2, C11.2, C12.2, C13.2, C14.2, C15.2, C16.2, C17.2, C18.2, C31.2, C32.2, C33.2, C34.2, C35.2, C36.2, C37.2, C38.2, C39.2, C40.2, C41.2, C42.2, C43.2, C44.2, C45.2, C46.2, C47.2, C48.2, C61.2, C62.2, C63.2, C64.2, C65.2, C66.2, C67.2, C68.2, C69.2, C70.2, C71.2, C72.2, R1.1, R2.1, R3.1, R4.1, R5.1, R6.1, R7.1, R8.1, R9.1, R10.1, R11.1, R12.1, R13.1, R14.1, R15.1, R16.1, R17.1, R18.1, R19.1, R20.1, R21.1, R22.1, R23.1, R24.1, R25.1, R26.1, R27.1, R28.1, R29.1, R30.1, R31.1, R32.1, R33.1, R34.1, R35.1, R36.1, R37.1, R38.1, R39.1, R40.1, R41.1, R42.1, R43.1, R44.1, R45.1, R46.1, R47.1, R48.1, R49.1, R50.1, R51.1, R52.1, R53.1, R54.1, R55.1, R56.1, R57.1, R58.1, R59.1, R60.1, R61.1, R62.1, R63.1, R64.1; also elsewhere on the board
PIN1: R1.2, TP1.TP, U5.1 (IN_A), U6.1 (IN_A), X2.1
PIN2: R9.2, TP2.TP, U5.5 (IN_B), U6.5 (IN_B), X2.2
PIN3: R17.2, TP3.TP, U6.10 (IN_C), U9.10 (IN_C), X2.3
PIN4: R25.2, TP4.TP, U6.6 (IN_D), U9.6 (IN_D), X2.4
PIN5: R2.2, TP5.TP, U1.1 (IN_A), U2.1 (IN_A), X2.5
PIN6: R10.2, TP6.TP, U1.5 (IN_B), U2.5 (IN_B), X2.6
PIN7: R18.2, TP7.TP, U2.10 (IN_C), U7.10 (IN_C), X2.7
PIN8: R26.2, TP8.TP, U2.6 (IN_D), U7.6 (IN_D), X2.8
PIN9: R3.2, TP9.TP, U3.1 (IN_A), U4.1 (IN_A), X2.9
PIN10: R11.2, TP10.TP, U3.5 (IN_B), U4.5 (IN_B), X2.10
PIN11: R19.2, TP11.TP, U4.10 (IN_C), U8.10 (IN_C), X2.11
PIN12: R27.2, TP12.TP, U4.6 (IN_D), U8.6 (IN_D), X2.12
PIN13: R4.2, TP13.TP, U14.1 (IN_A), U15.1 (IN_A), X2.13
PIN14: R12.2, TP14.TP, U14.5 (IN_B), U15.5 (IN_B), X2.14
PIN15: R20.2, TP15.TP, U15.10 (IN_C), U18.10 (IN_C), X2.15
PIN16: R28.2, TP16.TP, U15.6 (IN_D), U18.6 (IN_D), X2.16
PIN17: R5.2, TP17.TP, U10.1 (IN_A), U11.1 (IN_A), X2.17
PIN18: R13.2, TP18.TP, U10.5 (IN_B), U11.5 (IN_B), X2.18
PIN19: R21.2, TP19.TP, U11.10 (IN_C), U16.10 (IN_C), X2.19
PIN20: R29.2, TP20.TP, U11.6 (IN_D), U16.6 (IN_D), X2.20
PIN21: R6.2, TP21.TP, U12.1 (IN_A), U13.1 (IN_A), X2.21
PIN22: R14.2, TP22.TP, U12.5 (IN_B), U13.5 (IN_B), X2.22
PIN23: R22.2, TP23.TP, U13.10 (IN_C), U17.10 (IN_C), X2.23
PIN24: R30.2, TP24.TP, U13.6 (IN_D), U17.6 (IN_D), X2.24
PIN25: R7.2, TP25.TP, U21.1 (IN_A), U22.1 (IN_A), X2.25
PIN26: R15.2, TP26.TP, U21.5 (IN_B), U22.5 (IN_B), X2.26
PIN27: R23.2, TP27.TP, U22.10 (IN_C), U24.10 (IN_C), X2.27
PIN28: R31.2, TP28.TP, U22.6 (IN_D), U24.6 (IN_D), X2.28
PIN29: R8.2, TP29.TP, U19.1 (IN_A), U20.1 (IN_A), X2.29
PIN30: R16.2, TP30.TP, U19.5 (IN_B), U20.5 (IN_B), X2.30
PIN31: R24.2, TP31.TP, U20.10 (IN_C), U23.10 (IN_C), X2.31
PIN32: R32.2, TP32.TP, U20.6 (IN_D), U23.6 (IN_D), X2.32
V+: C7.1, C8.1, C9.1, C10.1, C11.1, C12.1, C16.1, C17.1, C18.1, C37.1, C38.1, C39.1, C40.1, C41.1, C42.1, C46.1, C47.1, C48.1, C65.1, C66.1, C67.1, C68.1, C71.1, C72.1, U1.3 (V+), U2.3 (V+), U3.3 (V+), U4.3 (V+), U5.3 (V+), U6.3 (V+), U7.3 (V+), U8.3 (V+), U9.3 (V+), U10.3 (V+), U11.3 (V+), U12.3 (V+), U13.3 (V+), U14.3 (V+), U15.3 (V+), U16.3 (V+), U17.3 (V+), U18.3 (V+), U19.3 (V+), U20.3 (V+), U21.3 (V+), U22.3 (V+), U23.3 (V+), U24.3 (V+); also elsewhere on the board
V-: C1.1, C2.1, C3.1, C4.1, C5.1, C6.1, C13.1, C14.1, C15.1, C31.1, C32.1, C33.1, C34.1, C35.1, C36.1, C43.1, C44.1, C45.1, C61.1, C62.1, C63.1, C64.1, C69.1, C70.1, U1.8 (V-), U2.8 (V-), U3.8 (V-), U4.8 (V-), U5.8 (V-), U6.8 (V-), U7.8 (V-), U8.8 (V-), U9.8 (V-), U10.8 (V-), U11.8 (V-), U12.8 (V-), U13.8 (V-), U14.8 (V-), U15.8 (V-), U16.8 (V-), U17.8 (V-), U18.8 (V-), U19.8 (V-), U20.8 (V-), U21.8 (V-), U22.8 (V-), U23.8 (V-), U24.8 (V-); also elsewhere on the board

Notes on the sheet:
TODO: Check if we want male or female D Sub

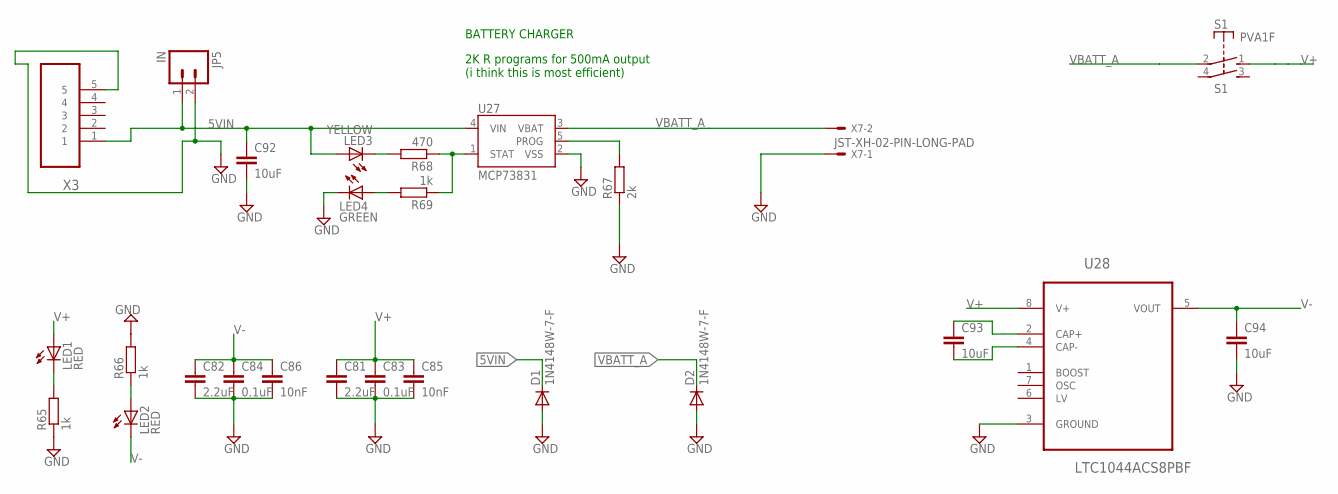
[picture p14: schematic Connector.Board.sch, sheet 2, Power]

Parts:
C81, C82: 2.2uF; C0805
C83, C84: 0.1uF; C0402
C85, C86: 10nF; C0402
C92, C93, C94: 10uF; C0805
D1, D2: 1N4148W-7-F; SOD123
JP5: IN; 1X02
LED1, LED2: RED; SML0805
LED3: YELLOW; SML0805
LED4: GREEN; SML0805
R65, R66, R69: 1k; R0402
R67: 2k; R0402
R68: 470; R0402
S1: PVA1F
U27: MCP73831; SOT23-5
U28: LTC1044ACS8PBF; SOIC127P600X175-8N
X3: 47346-0001; MOLEX_47346-0001
X7: JST-XH-02-PIN-LONG-PAD; JST-XH-02-PACKAGE-LONG-PAD

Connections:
5VIN: C92.1, D1.C, JP5.1, LED3.A, U27.4 (VIN), X3.1
BOOST: U28.1 (BOOST)
CHRG: LED3.C, R68.2
GND: C81.2, C82.2, C83.2, C84.2, C85.2, C86.2, C92.2, C94.2, D1.A, D2.A, JP5.2, LED4.C, R65.1, R66.2, R67.1, U27.2 (VSS), U28.3 (GROUND), X3.5, X7.1; also elsewhere on the board
unnamed: LED2.A, R66.1
unnamed: C93.1, U28.2 (CAP+)
unnamed: C93.2, U28.4 (CAP-)
unnamed: LED4.A, R69.2
unnamed: LED1.C, R65.2
PROG: R67.2, U27.5 (PROG)
STAT: R68.1, R69.1, U27.1 (STAT)
V+: C81.1, C83.1, C85.1, LED1.A, S1.1 (S), U28.8 (V+); also elsewhere on the board
V-: C82.1, C84.1, C86.1, C94.1, LED2.C, U28.5 (VOUT); also elsewhere on the board
VBATT_A: D2.C, S1.2, U27.3 (VBAT), X7.2

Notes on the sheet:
BATTERY CHARGER
2K R programs for 500mA output (i think this is most efficient)

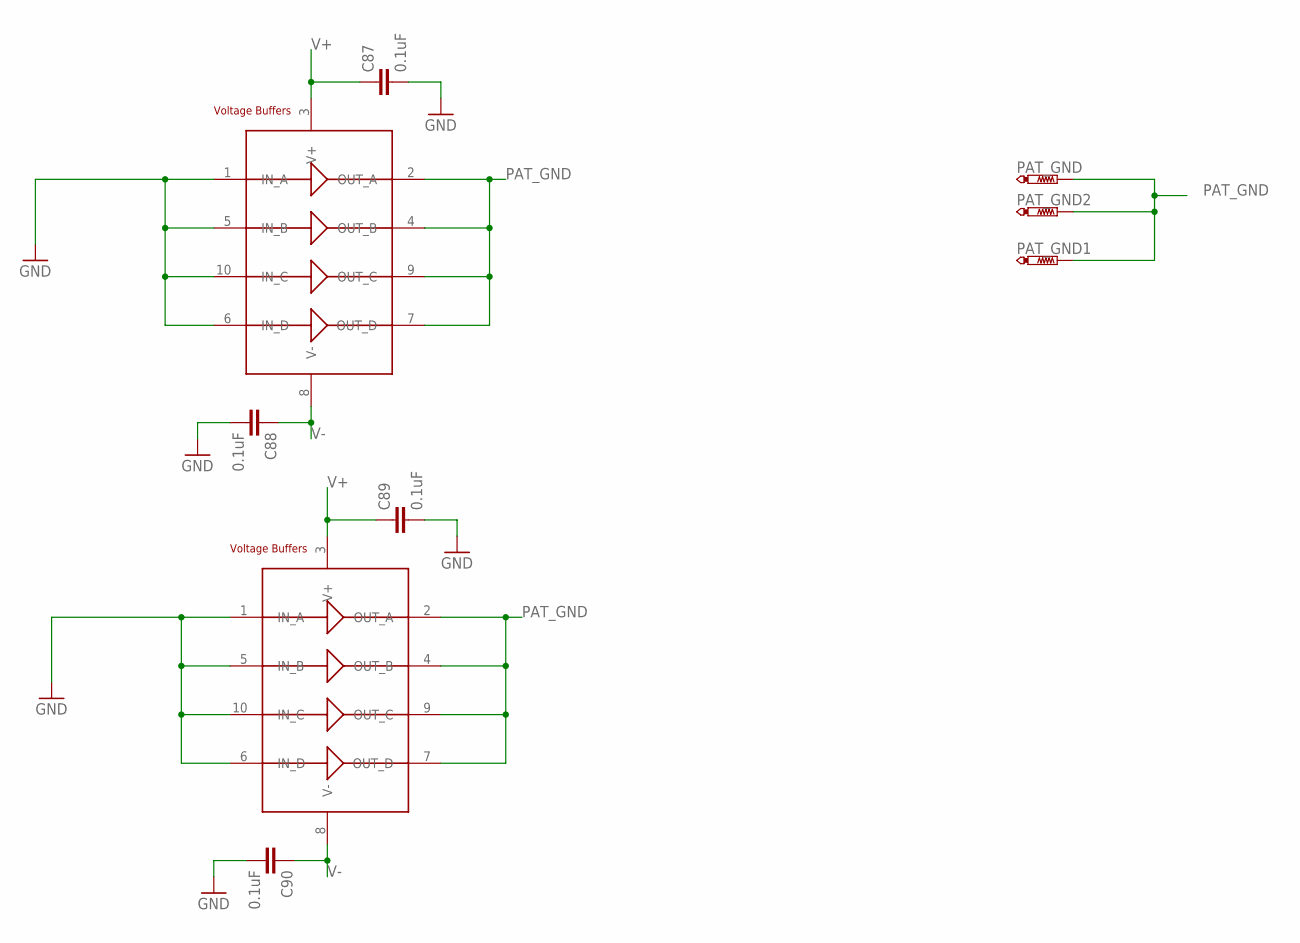
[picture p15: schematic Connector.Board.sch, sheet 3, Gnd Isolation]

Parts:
C87, C88, C89, C90: 0.1uF; C0402
PAT_GND, PAT_GND1, PAT_GND2: TOUCHPROOF; TOUCHPROOF_PIN
U25, U26: AD8244; MSOP10

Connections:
GND: C87.2, C88.2, C89.2, C90.2, U25.1 (IN_A), U25.5 (IN_B), U25.6 (IN_D), U25.10 (IN_C), U26.1 (IN_A), U26.5 (IN_B), U26.6 (IN_D), U26.10 (IN_C); also elsewhere on the board
PAT_GND: PAT_GND.TP, PAT_GND1.TP, PAT_GND2.TP, U25.2 (OUT_A), U25.4 (OUT_B), U25.7 (OUT_D), U25.9 (OUT_C), U26.2 (OUT_A), U26.4 (OUT_B), U26.7 (OUT_D), U26.9 (OUT_C)
V+: C87.1, C89.1, U25.3 (V+), U26.3 (V+); also elsewhere on the board
V-: C88.1, C90.1, U25.8 (V-), U26.8 (V-); also elsewhere on the board

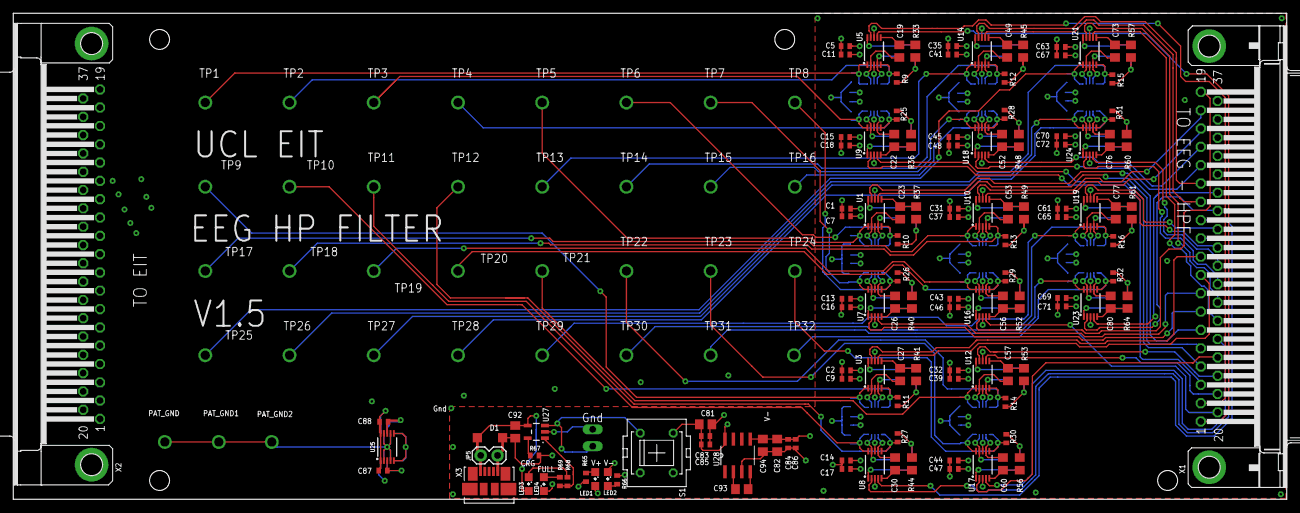
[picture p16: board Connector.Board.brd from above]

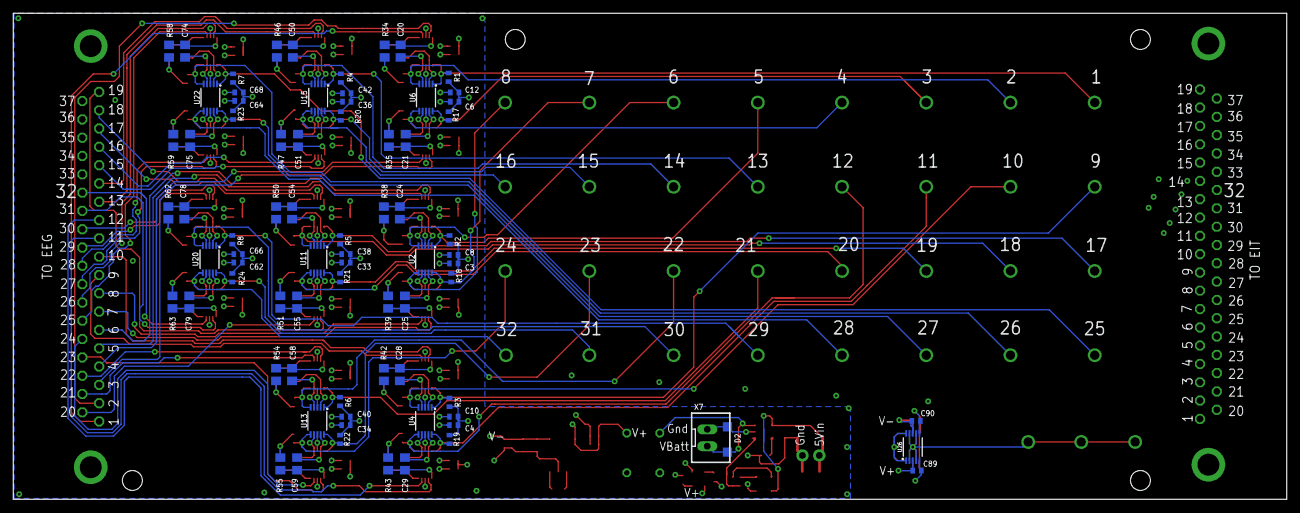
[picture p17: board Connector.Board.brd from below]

Board: 4 copper layers, 192.0 x 73.3 mm, 237 parts (77 on the bottom side), 142 nets.

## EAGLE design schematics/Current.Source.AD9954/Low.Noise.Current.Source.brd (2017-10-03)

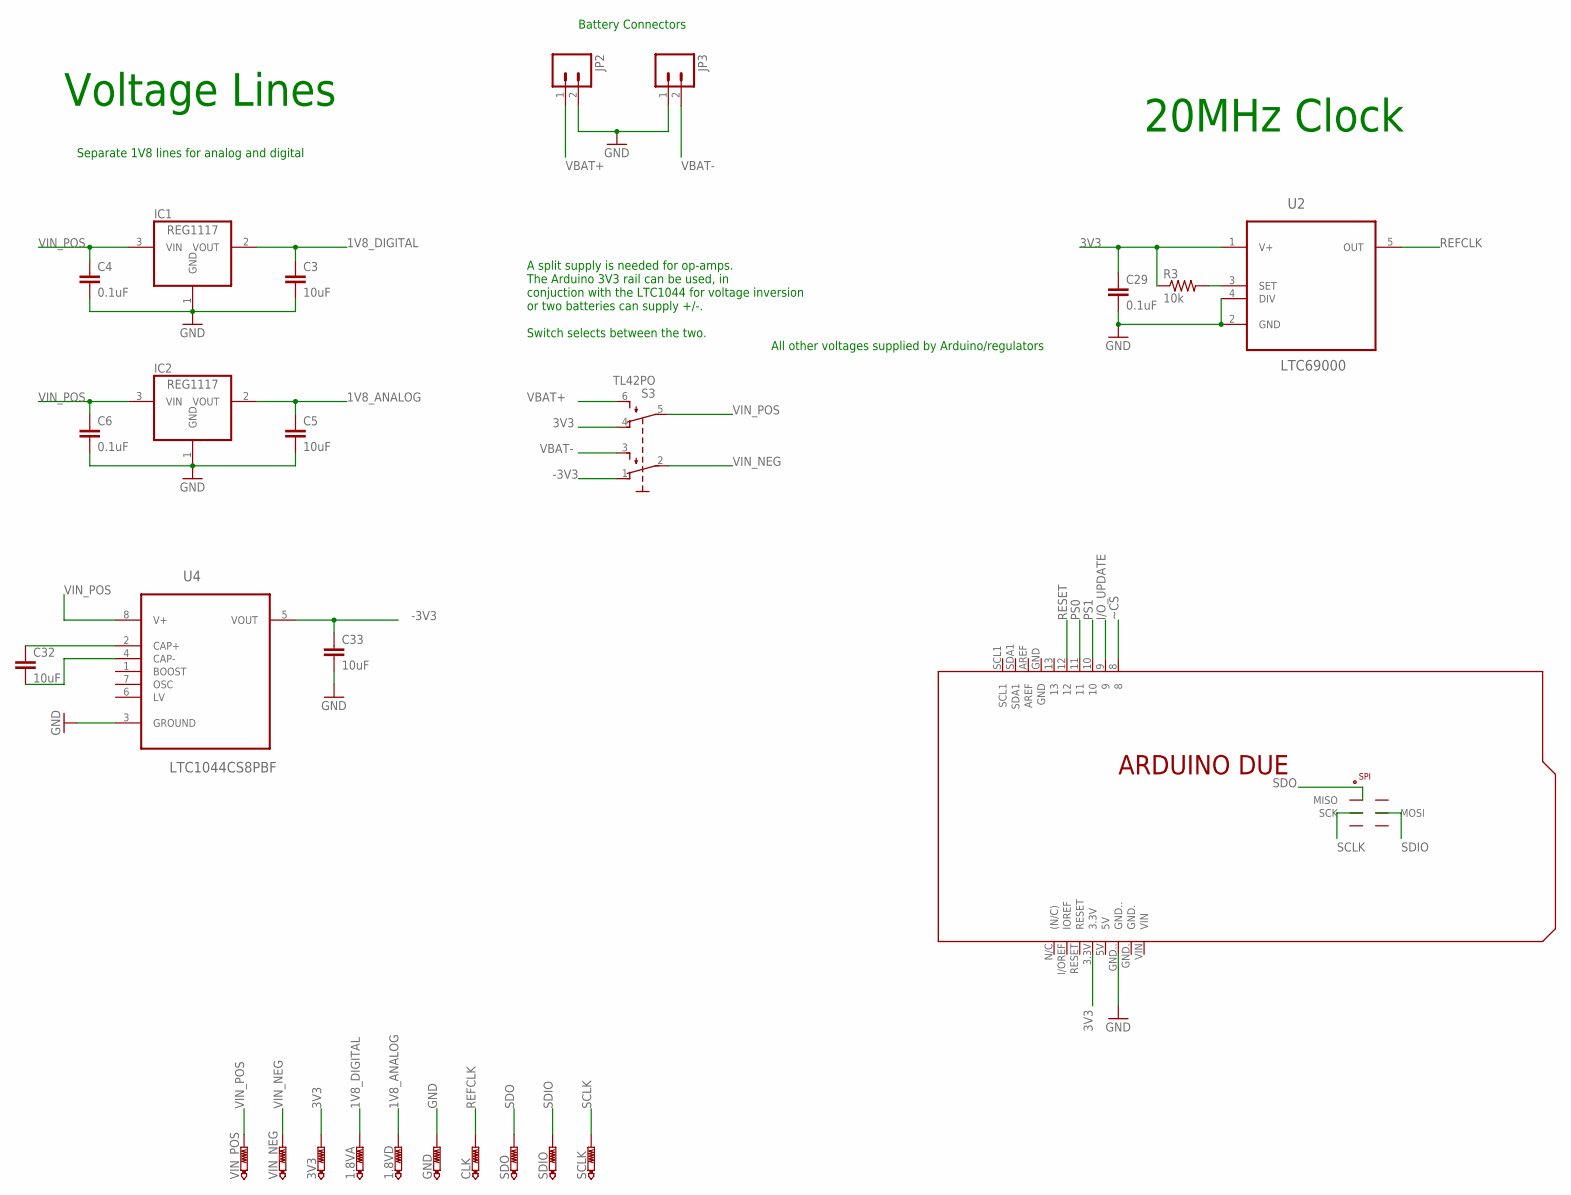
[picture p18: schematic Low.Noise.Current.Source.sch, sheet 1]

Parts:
1.8VA, 1.8VD, 3V3: PTR1PAD1-13; P1-13
C3, C5, C32, C33: 10uF; C0603
C4, C6, C29: 0.1uF; C0603
CLK: PTR1PAD1-13; P1-13
GND: PTR1PAD1-13; P1-13
IC1, IC2: REG1117; SOT223
JP2, JP3: M02-JST-2MM-SMT; JST-2-SMD
PCB1: ARDUINO_DUE
R3: 10k; R0805
S3: TL42PO; TL4XPO
SCLK: PTR1PAD1-13; P1-13
SDIO: PTR1PAD1-13; P1-13
SDO: PTR1PAD1-13; P1-13
U2: LTC69000; SOT23-5L
U4: LTC1044CS8PBF; SOIC127P600X175-8N
VIN_NEG: PTR1PAD1-13; P1-13
VIN_POS: PTR1PAD1-13; P1-13

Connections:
1V8_ANALOG: 1.8VD.TP, C5.1, IC2.2 (VOUT); also elsewhere on the board
1V8_DIGITAL: 1.8VA.TP, C3.1, IC1.2 (VOUT); also elsewhere on the board
3V3: 3V3.TP, C29.1, PCB1.3.3V, R3.1, S3.4 (O1), U2.1 (V+); also elsewhere on the board
-3V3: C33.1, S3.1 (O), U4.5 (VOUT)
GND: C3.2, C4.2, C5.2, C6.2, C29.2, C33.2, GND.TP, IC1.1 (GND), IC2.1 (GND), JP2.2, JP3.1, PCB1.GND.., U2.2 (GND), U2.4 (DIV), U4.3 (GROUND); also elsewhere on the board
I/O_UPDATE: PCB1.9; also elsewhere on the board
unnamed: C32.1, U4.2 (CAP+)
unnamed: R3.2, U2.3 (SET)
unnamed: C32.2, U4.4 (CAP-)
PS0: PCB1.11; also elsewhere on the board
PS1: PCB1.10; also elsewhere on the board
REFCLK: CLK.TP, U2.5 (OUT); also elsewhere on the board
RESET: PCB1.12; also elsewhere on the board
SCLK: PCB1.SCK, SCLK.TP; also elsewhere on the board
SDIO: PCB1.MOSI, SDIO.TP; also elsewhere on the board
SDO: PCB1.MISO, SDO.TP; also elsewhere on the board
VBAT+: JP2.1, S3.6 (S1)
VBAT-: JP3.2, S3.3 (S)
VIN_NEG: S3.2, VIN_NEG.TP; also elsewhere on the board
VIN_POS: C4.1, C6.1, IC1.3 (VIN), IC2.3 (VIN), S3.5 (P1), U4.8 (V+), VIN_POS.TP; also elsewhere on the board
~CS: PCB1.8; also elsewhere on the board

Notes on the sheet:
Separate 1V8 lines for analog and digital
Voltage Lines
20MHz Clock
A split supply is needed for op-amps. The Arduino 3V3 rail can be used, in conjuction with the LTC1044 for voltage inversion or two batteries can supply +/-. Switch selects between the two.
Battery Connectors
All other voltages supplied by Arduino/regulators

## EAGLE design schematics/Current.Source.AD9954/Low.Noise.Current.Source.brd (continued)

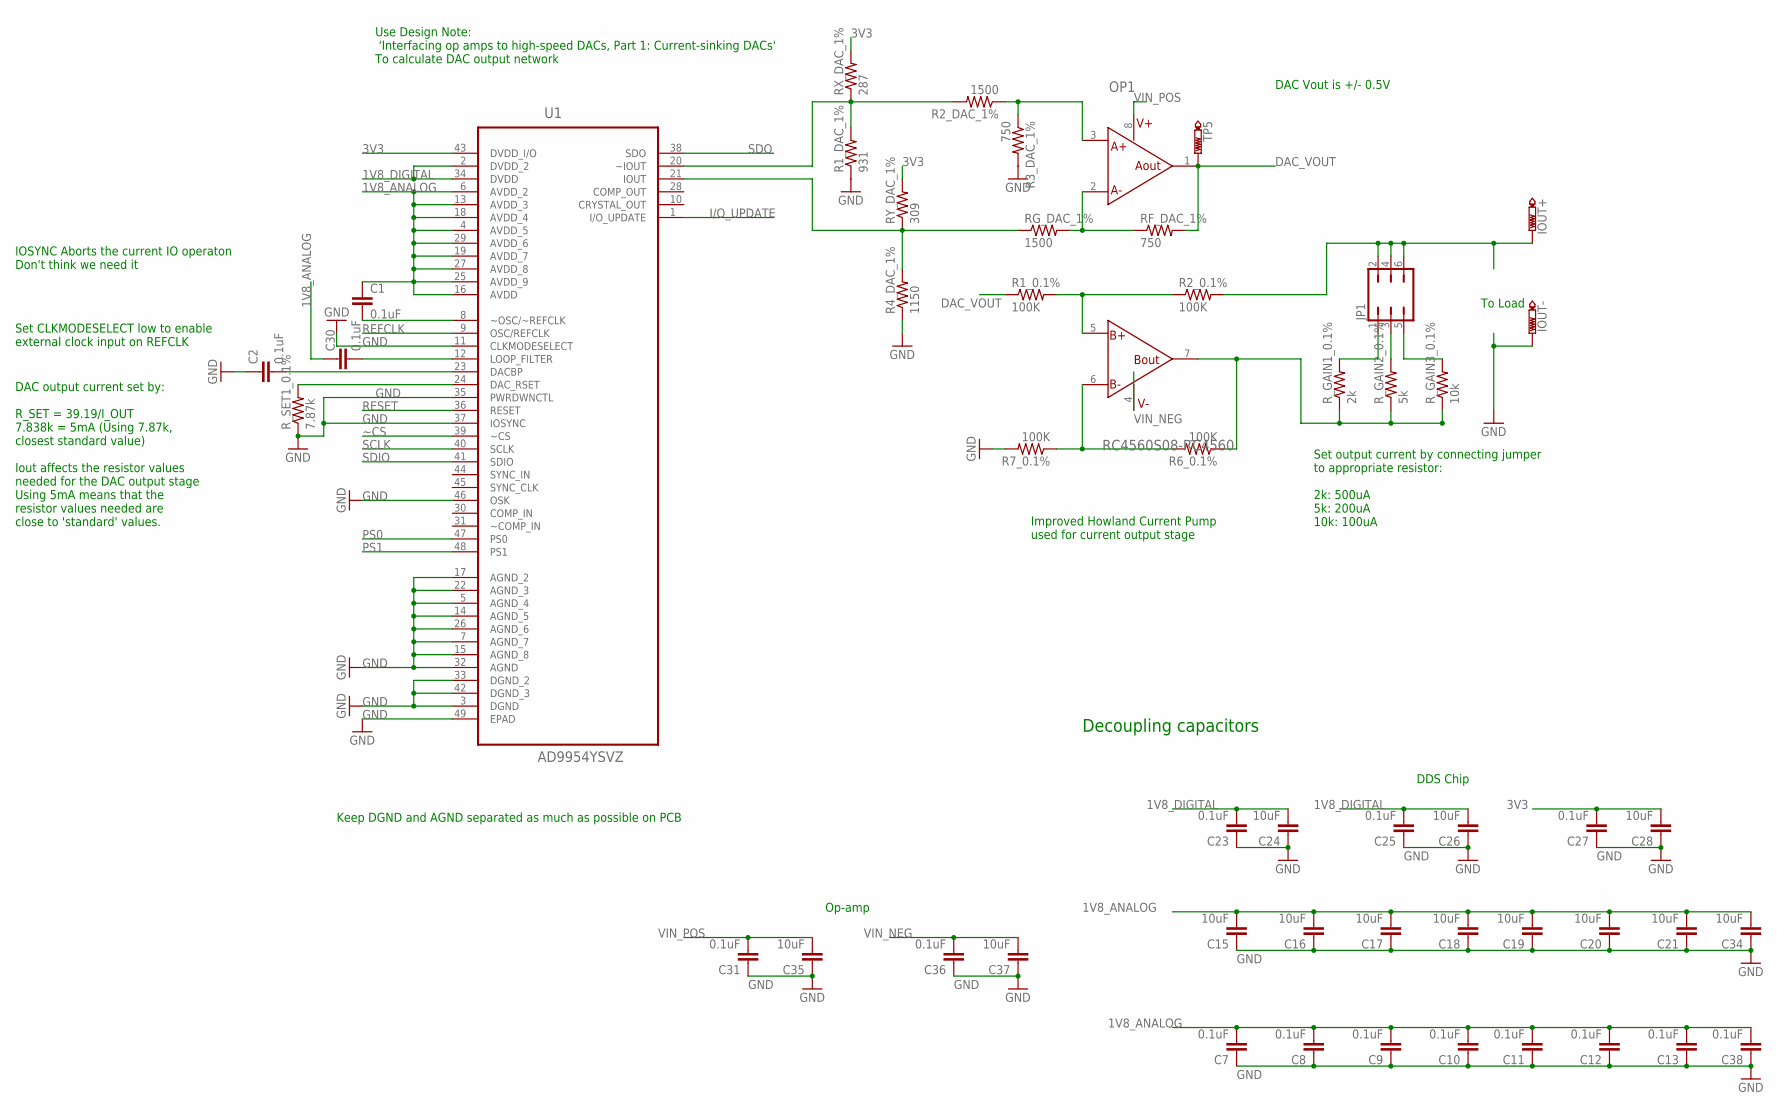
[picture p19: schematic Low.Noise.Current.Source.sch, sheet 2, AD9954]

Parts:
C1, C2, C7, C8, C9, C10, C11, C12, C13, C23, C25, C27, C30, C31, C36, C38: 0.1uF; C0603
C15, C16, C17, C18, C19, C20, C21, C24, C26, C28, C34, C35, C37: 10uF; C0603
IOUT+: PTR1PAD1-13; P1-13
IOUT-: PTR1PAD1-13; P1-13
JP1: JP3Q
OP1: RC4560S08-RC4560; SO8
R1_0.1%, R2_0.1%, R6_0.1%, R7_0.1%: 100K; R0805
R1_DAC_1%: 931; R0805
R2_DAC_1%: 1500; R0805
R3_DAC_1%: 750; R0805
R4_DAC_1%: 1150; R0805
RF_DAC_1%: 750; R0805
RG_DAC_1%: 1500; R0805
RX_DAC_1%: 287; R0805
RY_DAC_1%: 309; R0805
R_GAIN1_0.1%: 2k; R0805
R_GAIN2_0.1%: 5k; R0805
R_GAIN3_0.1%: 10k; R0805
R_SET1_0.1%: 7.87k; R0805
TP5: PTR1PAD1-13; P1-13
U1: AD9954YSVZ; QFP50P900X900X120-49N

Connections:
1V8_ANALOG: C1.1, C7.2, C8.2, C9.2, C10.2, C11.2, C12.2, C13.2, C15.2, C16.2, C17.2, C18.2, C19.2, C20.2, C21.2, C30.1, C34.2, C38.2, U1.4 (AVDD_5), U1.6 (AVDD_2), U1.13 (AVDD_3), U1.16 (AVDD), U1.18 (AVDD_4), U1.19 (AVDD_7), U1.25 (AVDD_9), U1.27 (AVDD_8), U1.29 (AVDD_6); also elsewhere on the board
1V8_DIGITAL: C23.2, C24.2, C25.2, C26.2, U1.2 (DVDD_2), U1.34 (DVDD); also elsewhere on the board
3V3: C27.2, C28.2, RX_DAC_1%.2, RY_DAC_1%.2, U1.43 (DVDD_I/O); also elsewhere on the board
DAC_VOUT: OP1.1 (OUTA), R1_0.1%.1, RF_DAC_1%.2, TP5.TP
GND: C2.1, C7.1, C8.1, C9.1, C10.1, C11.1, C12.1, C13.1, C15.1, C16.1, C17.1, C18.1, C19.1, C20.1, C21.1, C23.1, C24.1, C25.1, C26.1, C27.1, C28.1, C31.1, C34.1, C35.1, C36.1, C37.1, C38.1, IOUT-.TP, R1_DAC_1%.1, R3_DAC_1%.2, R4_DAC_1%.1, R7_0.1%.2, R_SET1_0.1%.1, U1.3 (DGND), U1.5 (AGND_4), U1.7 (AGND_7), U1.11 (CLKMODESELECT), U1.14 (AGND_5), U1.15 (AGND_8), U1.17 (AGND_2), U1.22 (AGND_3), U1.26 (AGND_6), U1.32 (AGND), U1.33 (DGND_2), U1.35 (PWRDWNCTL), U1.37 (IOSYNC), U1.42 (DGND_3), U1.46 (OSK), U1.49 (EPAD); also elsewhere on the board
I/O_UPDATE: U1.1 (I/O_UPDATE); also elsewhere on the board
IOUT: R4_DAC_1%.2, RG_DAC_1%.1, RY_DAC_1%.1, U1.21 (IOUT)
unnamed: C2.2, U1.23 (DACBP)
unnamed: C1.2, U1.8 (~OSC/~REFCLK)
unnamed: R_SET1_0.1%.2, U1.24 (DAC_RSET)
unnamed: OP1.3 (POSA), R2_DAC_1%.1, R3_DAC_1%.1
unnamed: OP1.5 (POSB), R1_0.1%.2, R2_0.1%.1
unnamed: OP1.2 (NEGA), RF_DAC_1%.1, RG_DAC_1%.2
unnamed: OP1.6 (NEGB), R6_0.1%.2, R7_0.1%.1
unnamed: OP1.7 (OUTB), R6_0.1%.1, R_GAIN1_0.1%.1, R_GAIN2_0.1%.1, R_GAIN3_0.1%.1
unnamed: C30.2, U1.12 (LOOP_FILTER)
unnamed: IOUT+.TP, JP1.2, JP1.4, JP1.6, R2_0.1%.2
unnamed: JP1.3, R_GAIN2_0.1%.2
unnamed: JP1.5, R_GAIN3_0.1%.2
unnamed: JP1.1, R_GAIN1_0.1%.2
PS0: U1.47 (PS0); also elsewhere on the board
PS1: U1.48 (PS1); also elsewhere on the board
REFCLK: U1.9 (OSC/REFCLK); also elsewhere on the board
RESET: U1.36 (RESET); also elsewhere on the board
SCLK: U1.40 (SCLK); also elsewhere on the board
SDIO: U1.41 (SDIO); also elsewhere on the board
SDO: U1.38 (SDO); also elsewhere on the board
VIN_NEG: C36.2, C37.2, OP1.4 (V-); also elsewhere on the board
VIN_POS: C31.2, C35.2, OP1.8 (V+); also elsewhere on the board
~CS: U1.39 (~CS); also elsewhere on the board
~IOUT: R1_DAC_1%.2, R2_DAC_1%.2, RX_DAC_1%.1, U1.20 (~IOUT)

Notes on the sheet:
Set CLKMODESELECT low to enable external clock input on REFCLK
DAC output current set by: R_SET = 39.19/I_OUT 7.838k = 5mA (Using 7.87k, closest standard value) Iout affects the resistor values needed for the DAC output stage Using 5mA means that the resistor values needed are close to 'standard' values.
IOSYNC Aborts the current IO operaton Don't think we need it
Decoupling capacitors
Use Design Note: 'Interfacing op amps to high-speed DACs, Part 1: Current-sinking DACs' To calculate DAC output network
Keep DGND and AGND separated as much as possible on PCB
DAC Vout is +/- 0.5V
DDS Chip
Op-amp
Set output current by connecting jumper to appropriate resistor: 2k: 500uA 5k: 200uA 10k: 100uA
To Load
Improved Howland Current Pump used for current output stage

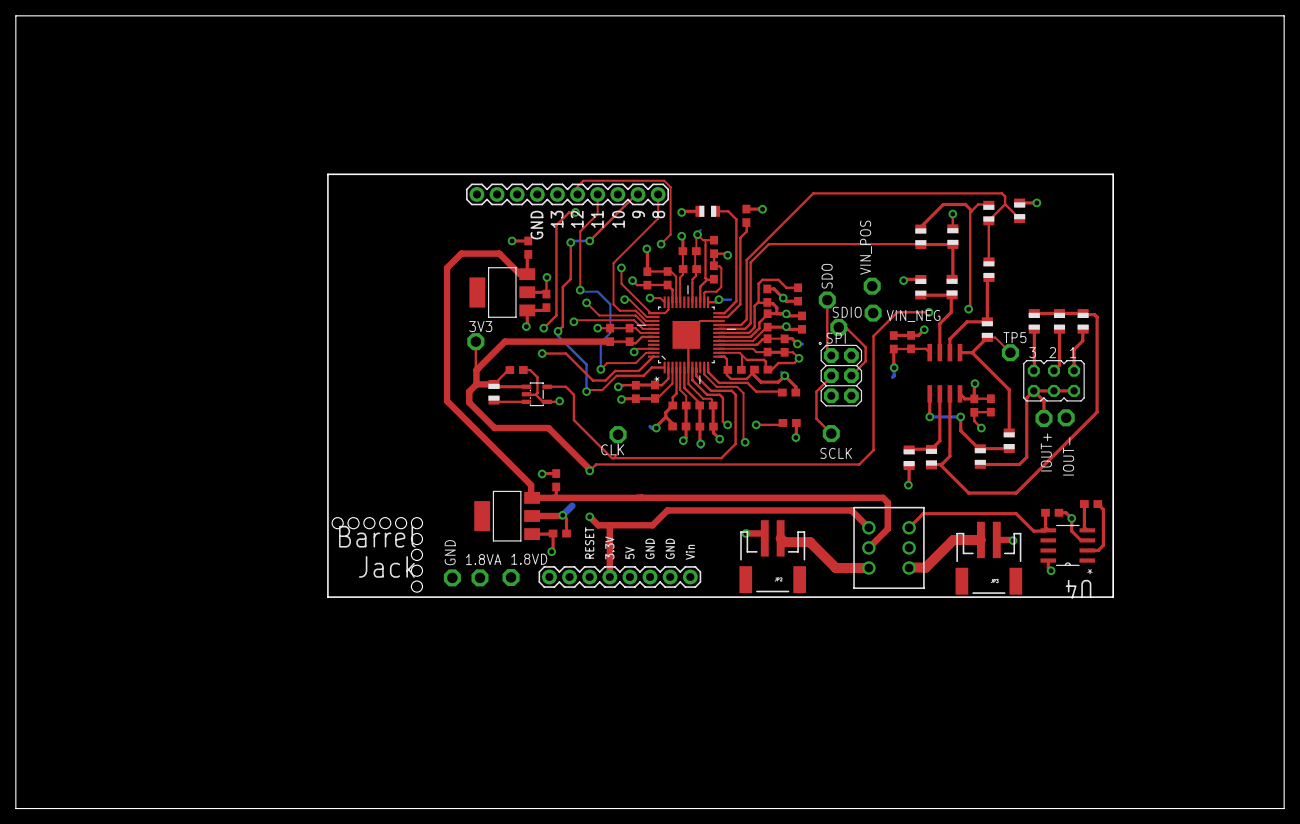
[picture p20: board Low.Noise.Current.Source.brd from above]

Board: 4 copper layers, 160.0 x 100.0 mm, 77 parts (0 on the bottom side), 37 nets.

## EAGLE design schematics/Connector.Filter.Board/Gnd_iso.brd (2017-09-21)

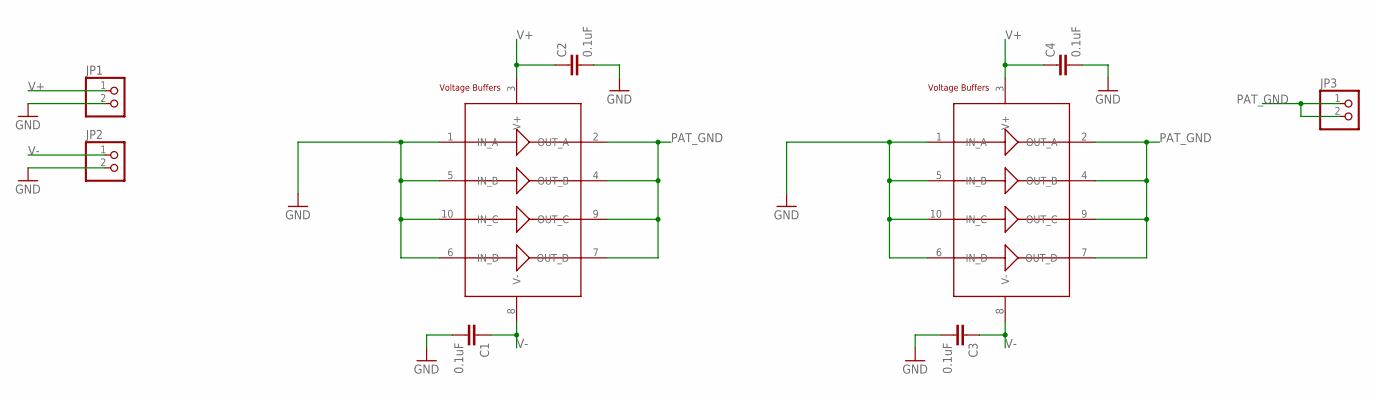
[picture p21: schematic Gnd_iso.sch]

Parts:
C1, C2, C3, C4: 0.1uF; C0805
JP1, JP2, JP3: PINHD-1X2/90; 1X02/90
U1, U2: AD8244; MSOP10

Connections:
GND: C1.2, C2.2, C3.2, C4.2, JP1.2, JP2.2, U1.1 (IN_A), U1.5 (IN_B), U1.6 (IN_D), U1.10 (IN_C), U2.1 (IN_A), U2.5 (IN_B), U2.6 (IN_D), U2.10 (IN_C)
PAT_GND: JP3.1, JP3.2, U1.2 (OUT_A), U1.4 (OUT_B), U1.7 (OUT_D), U1.9 (OUT_C), U2.2 (OUT_A), U2.4 (OUT_B), U2.7 (OUT_D), U2.9 (OUT_C)
V+: C2.1, C4.1, JP1.1, U1.3 (V+), U2.3 (V+)
V-: C1.1, C3.1, JP2.1, U1.8 (V-), U2.8 (V-)

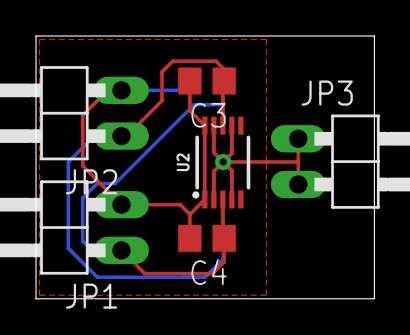
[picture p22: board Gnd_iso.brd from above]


Board: 2 copper layers, 18.8 x 14.6 mm, 9 parts (3 on the bottom side), 4 nets.

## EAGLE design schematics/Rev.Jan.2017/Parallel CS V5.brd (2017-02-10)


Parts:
CLOCK: LTC69000; SOT23-5L
C_CLK_BYP: 0.1u; C0805
JP+: PWR; JST-2-SMD
JP-: PWR; JST-2-SMD
LED_VDD: LEDSML0805; SML0805
LED_VSS: LEDSML0805; SML0805
R1, R3, R5, R7, R9, R10: 10k; R0805
R2, R4, R6, R8, R12, R13: 20k; R0805
R11: 1.5k; R0805
R_SET: 20k; R0805
R_VDD_LED: 1k; M0805
R_VSS_LED: 1k; M0805
S1, S2: PVA1F
TP_MCLK: PTR1PAD1-13; P1-13
TP_SCLK: PTR1PAD1-13; P1-13
TP_SDATA: PTR1PAD1-13; P1-13
TP_VDD: PTR1PAD1-13; P1-13
TP_VSS: PTR1PAD1-13; P1-13
U1: ADG714BRUZ; SOP65P640X120-24N
U$1: NANO

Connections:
CLK_OUT: CLOCK.5 (OUT), TP_MCLK.TP; also elsewhere on the board
DDS_SCLK: R1.1, R2.2, TP_SCLK.TP; also elsewhere on the board
DDS_SCLK_5V: R1.2, U$1.D13
DDS_SDATA: R3.1, R4.2, TP_SDATA.TP; also elsewhere on the board
FSYNC_CS1: U1.6 (D1); also elsewhere on the board
FSYNC_CS2: U1.8 (D2)
FSYNC_CS3: U1.10 (D3)
FSYNC_CS4: U1.12 (D4)
FSYNC_CS5: U1.13 (D5)
FSYNC_CS6: U1.15 (D6)
FSYNC_CS7: U1.17 (D7)
FSYNC_CS8: U1.19 (D8)
FSYNC_IN: R11.2, U1.5 (S1), U1.7 (S2), U1.9 (S3), U1.11 (S4), U1.14 (S5), U1.16 (S6), U1.18 (S7), U1.20 (S8)
FSYNC_IN_5V: R11.1, U$1.D5
GND: CLOCK.2 (GND), CLOCK.4 (DIV), C_CLK_BYP.2, LED_VDD.C, LED_VSS.C, R2.1, R4.1, R6.2, R8.2, R12.1, R13.1, S1.3 (S), S2.1 (S), U1.4 (GND), U1.21 (VSS), U$1.GND; also elsewhere on the board
unnamed: CLOCK.3 (SET), R_SET.2
unnamed: JP+.2, S1.2
unnamed: JP+.1, S1.4
unnamed: JP-.2, S2.2
unnamed: JP-.1, S2.4
unnamed: LED_VDD.A, R_VDD_LED.1
unnamed: LED_VSS.A, R_VSS_LED.1
unnamed: R3.2, U$1.D11
SW_DIN: R7.2, R8.1, U1.3 (DIN)
SW_DIN_5V: R7.1, U$1.D4
SW_SCLK: R5.2, R6.1, U1.1 (SCLK)
SW_SCLK_5V: R5.1, U$1.D9
SW_~RESET: R10.2, R13.2, U1.23 (~RESET)
SW_~RESET_5V: R10.1, U$1.D3
SW_~SYNC: R9.2, R12.2, U1.24 (~SYNC)
SW_~SYNC_5V: R9.1, U$1.D2
VDD: CLOCK.1 (V+), C_CLK_BYP.1, R_SET.1, R_VDD_LED.2, S1.1 (S), TP_VDD.TP, U1.2 (VDD); also elsewhere on the board
VSS: R_VSS_LED.2, S2.3 (S), TP_VSS.TP; also elsewhere on the board

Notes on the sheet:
Switch to route FSYNC to each CS
5V from Arduino needs to be convertred to ~3.3V to set the right levels for the DDS & Switch ICs, which are powered by 3.7V batteries. Hence resistor dividers.
Battery Connector & Power LEDs
Clock output Freq = 10MHz * 20k/R_set
Arduino Socket
Test Points
Left floating - is routed to the FSYNC pins of DDS chips which have a resistor to GND to form a potential divider, giving the correct voltage level for DDS IC


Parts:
C_DDS1: 0.1u; C0805
C_DDS2: 10u; C0805
C_DDS3: 10n; C0805
C_DDS4: 100n; C0805
C_DECOUP: 1u; C0805
C_OPA1, C_OPA2: 0.1u; C0805
C_OPB1, C_OPB2: 0.1u; C0805
C_OPC1, C_OPC2: 0.1u; C0805
C_OPD1, C_OPD2: 0.1u; C0805
DDS: AD9833BRMZ; SOP50P490X110-10N
JP_OUT: JP1Q; JP1
OP_GAIN: RC4560S08-RC4560; SO8
OP_HOWLA: RC4560S08-RC4560; SO8
OP_HOWLB: RC4560S08-RC4560; SO8
OP_S2D: RC4560S08-RC4560; SO8
R_DECOUP: 10k; R0805
R_GAIN1: 10k; R0805
R_GAIN2: 1; R0805
R_GAINF: POTENTIOMETER_PT-10; PT-10
R_HOWA1, R_HOWA2, R_HOWA3, R_HOWA4: 100k; R0805
R_HOWA5: 10k; R0805
R_HOWB1, R_HOWB2, R_HOWB3, R_HOWB5: 100k; R0805
R_HOWB4: 10k; R0805
R_PULLDOWN: 20k; R0805
R_S2D1, R_S2D2, R_S2D3, R_S2D4: 10k; R0805
TP_FSYNC: PTR1PAD1-13; P1-13
TP_GND: PTR1PAD1-13; P1-13
TP_VSIN, TP_VSIN1, TP_VSIN2, TP_VSIN3: PTR1PAD1-13; P1-13

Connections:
CLK_OUT: DDS.5 (MCLK); also elsewhere on the board
COMP: C_DDS3.2, DDS.1 (COMP)
DDS_SCLK: DDS.7 (SCLK); also elsewhere on the board
DDS_SDATA: DDS.6 (SDATA); also elsewhere on the board
FSYNC_CS1: DDS.8 (FSYNC), R_PULLDOWN.2, TP_FSYNC.TP; also elsewhere on the board
GND: C_DDS1.2, C_DDS2.2, C_DDS4.1, C_OPA1.2, C_OPA2.2, C_OPB1.2, C_OPB2.2, C_OPC1.2, C_OPC2.2, C_OPD1.2, C_OPD2.2, DDS.4 (DGND), DDS.9 (AGND), R_DECOUP.2, R_GAIN1.1, R_PULLDOWN.1, R_S2D2.2, TP_GND.TP; also elsewhere on the board
unnamed: C_DDS4.2, DDS.3 (CAP/2.5V)
unnamed: OP_GAIN.1 (OUTA), R_GAIN2.1, R_GAINF.3, R_S2D3.2, R_S2D4.2, TP_VSIN1.TP
unnamed: OP_S2D.6 (NEGB), OP_S2D.7 (OUTB), R_HOWA1.2, R_HOWB1.2, TP_VSIN3.TP
unnamed: OP_GAIN.2 (NEGA), R_GAIN1.2, R_GAIN2.2, R_GAINF.1
unnamed: OP_S2D.5 (POSB), R_S2D4.1
unnamed: OP_HOWLA.5 (POSB), R_HOWA1.1, R_HOWA3.1
unnamed: OP_S2D.3 (POSA), R_S2D2.1
unnamed: OP_S2D.2 (NEGA), R_S2D1.2, R_S2D3.1
unnamed: OP_HOWLB.3 (POSA), R_HOWB2.1, R_HOWB3.1
unnamed: OP_HOWLB.2 (NEGA), R_HOWB1.1, R_HOWB5.1
unnamed: JP_OUT.2, R_HOWB3.2, R_HOWB4.1
unnamed: JP_OUT.1, R_HOWA3.2, R_HOWA5.2
unnamed: OP_HOWLA.7 (OUTB), R_HOWA4.1, R_HOWA5.1
unnamed: OP_HOWLA.6 (NEGB), R_HOWA2.1, R_HOWA4.2
unnamed: OP_HOWLB.1 (OUTA), R_HOWB4.2, R_HOWB5.2
unnamed: OP_S2D.1 (OUTA), R_HOWA2.2, R_HOWB2.2, R_S2D1.1, TP_VSIN2.TP
VDD: C_DDS1.1, C_DDS2.1, C_DDS3.1, C_OPA1.1, C_OPB1.1, C_OPC1.1, C_OPD1.1, DDS.2 (VDD), OP_GAIN.8 (V+), OP_HOWLA.8 (V+), OP_HOWLB.8 (V+), OP_S2D.8 (V+); also elsewhere on the board
VOUT: C_DECOUP.1, DDS.10 (VOUT), TP_VSIN.TP
VSIN: C_DECOUP.2, OP_GAIN.3 (POSA), R_DECOUP.1
VSS: C_OPA2.1, C_OPB2.1, C_OPC2.1, C_OPD2.1, OP_GAIN.4 (V-), OP_HOWLA.4 (V-), OP_HOWLB.4 (V-), OP_S2D.4 (V-); also elsewhere on the board

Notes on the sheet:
DDS Chip, programmed by SPI
Howland Current Pump Using two separate ICs for medical safety to cover case where a single device fails.
Power Bypass Caps for Op Amps
Gain Stage Can either put in fixed resistor (R_gain2) or potentiometer for setting gain
Single ended to differential


Board: 4 copper layers, 99.9 x 150.1 mm, 75 parts (0 on the bottom side), 45 nets.

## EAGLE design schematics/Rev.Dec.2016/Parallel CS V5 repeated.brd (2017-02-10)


Board: 4 copper layers, 99.9 x 150.1 mm, 290 parts (0 on the bottom side), 145 nets.

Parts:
CLOCK: LTC69000; SOT23-5L
C_CLK_BYP: 0.1u; C0805
C_DDS1, C_DDS5, C_DDS9, C_DDS13, C_DDS17, C_DDS21: 0.1u; C0805
C_DDS2, C_DDS6, C_DDS10, C_DDS14, C_DDS18, C_DDS22: 10u; C0805
C_DDS3, C_DDS7, C_DDS11, C_DDS15, C_DDS19, C_DDS23: 10n; C0805
C_DDS4, C_DDS8, C_DDS12, C_DDS16, C_DDS20, C_DDS24: 100n; C0805
C_DECOUP, C_DECOUP1, C_DECOUP2, C_DECOUP3, C_DECOUP4, C_DECOUP5: 1u; C0805
C_OPA1, C_OPA2, C_OPA3, C_OPA4, C_OPA5, C_OPA6, C_OPA7, C_OPA8, C_OPA9, C_OPA10, C_OPA11, C_OPA12: 0.1u; C0805
C_OPB1, C_OPB2, C_OPB3, C_OPB4, C_OPB5, C_OPB6, C_OPB7, C_OPB8, C_OPB9, C_OPB10, C_OPB11, C_OPB12: 0.1u; C0805
C_OPC1, C_OPC2, C_OPC3, C_OPC4, C_OPC5, C_OPC6, C_OPC7, C_OPC8, C_OPC9, C_OPC10, C_OPC11, C_OPC12: 0.1u; C0805
C_OPD1, C_OPD2, C_OPD3, C_OPD4, C_OPD5, C_OPD6, C_OPD7, C_OPD8, C_OPD9, C_OPD10, C_OPD11, C_OPD12: 0.1u; C0805
DDS, DDS1, DDS2, DDS3, DDS4, DDS5: AD9833BRMZ; SOP50P490X110-10N
JP+: PWR; JST-2-SMD
JP-: PWR; JST-2-SMD
JP_OUT, JP_OUT1, JP_OUT2, JP_OUT3, JP_OUT4, JP_OUT5: JP1
LED_VDD: SML0805
LED_VSS: SML0805
OP_GAIN, OP_GAIN1, OP_GAIN2, OP_GAIN3, OP_GAIN4, OP_GAIN5: RC4560SOP65; SOP65P490X109-8N
OP_HOWLA, OP_HOWLA1, OP_HOWLA2, OP_HOWLA3, OP_HOWLA4, OP_HOWLA5: RC4560SOP65; SOP65P490X109-8N
OP_HOWLB, OP_HOWLB1, OP_HOWLB2, OP_HOWLB3, OP_HOWLB4, OP_HOWLB5: RC4560SOP65; SOP65P490X109-8N
OP_S2D, OP_S2D1, OP_S2D2, OP_S2D3, OP_S2D4, OP_S2D5: RC4560SOP65; SOP65P490X109-8N
R1, R3, R5, R7, R9, R10, R11: 10k; R0805
R2, R4, R6, R8, R12, R13: 20k; R0805
R_DECOUP, R_DECOUP1, R_DECOUP2, R_DECOUP3, R_DECOUP4, R_DECOUP5: 10k; R0805
R_GAIN1, R_GAIN3, R_GAIN5, R_GAIN7, R_GAIN9, R_GAIN11: 10k; R0805
R_GAIN2, R_GAIN4, R_GAIN6, R_GAIN8, R_GAIN10, R_GAIN12: 1; R0805
R_GAINF, R_GAINF1, R_GAINF2, R_GAINF3, R_GAINF4, R_GAINF5: PT-10
R_HOWA1, R_HOWA2, R_HOWA3, R_HOWA4, R_HOWA6, R_HOWA7, R_HOWA8, R_HOWA9, R_HOWA11, R_HOWA12, R_HOWA13, R_HOWA14, R_HOWA16, R_HOWA17, R_HOWA18, R_HOWA19, R_HOWA21, R_HOWA22, R_HOWA23, R_HOWA24, R_HOWA26, R_HOWA27, R_HOWA28, R_HOWA29: 100k; R0805
R_HOWA5, R_HOWA10, R_HOWA15, R_HOWA20, R_HOWA25, R_HOWA30: 10k; R0805
R_HOWB1, R_HOWB2, R_HOWB3, R_HOWB5, R_HOWB6, R_HOWB7, R_HOWB9, R_HOWB10, R_HOWB11, R_HOWB12, R_HOWB14, R_HOWB15, R_HOWB16, R_HOWB17, R_HOWB19, R_HOWB20, R_HOWB21, R_HOWB22, R_HOWB24, R_HOWB25, R_HOWB26, R_HOWB27, R_HOWB29, R_HOWB30: 100k; R0805
R_HOWB4, R_HOWB8, R_HOWB13, R_HOWB18, R_HOWB23, R_HOWB28: 10k; R0805
R_PULLDOWN, R_PULLDOWN1, R_PULLDOWN2, R_PULLDOWN3, R_PULLDOWN4, R_PULLDOWN5: 20k; R0805
R_S2D1, R_S2D2, R_S2D3, R_S2D4, R_S2D5, R_S2D6, R_S2D7, R_S2D8, R_S2D9, R_S2D10, R_S2D11, R_S2D12, R_S2D13, R_S2D14, R_S2D15, R_S2D16, R_S2D17, R_S2D18, R_S2D19, R_S2D20, R_S2D21, R_S2D22, R_S2D23, R_S2D24: 10k; R0805
R_SET: 20k; R0805
R_VDD_LED: 1k; M0805
R_VSS_LED: 1k; M0805
S1, S2: PVA1F
TP_FSYNC, TP_FSYNC1, TP_FSYNC2, TP_FSYNC3, TP_FSYNC4, TP_FSYNC5: PTR1PAD1-13; P1-13
TP_GND: PTR1PAD1-13; P1-13
TP_MCLK: PTR1PAD1-13; P1-13
TP_SCLK: PTR1PAD1-13; P1-13
TP_SDATA: PTR1PAD1-13; P1-13
TP_VDD: PTR1PAD1-13; P1-13
TP_VSIN, TP_VSIN1, TP_VSIN2, TP_VSIN3, TP_VSIN4, TP_VSIN5, TP_VSIN6, TP_VSIN7, TP_VSIN8, TP_VSIN9, TP_VSIN10, TP_VSIN11, TP_VSIN12, TP_VSIN13, TP_VSIN14, TP_VSIN15, TP_VSIN16, TP_VSIN17, TP_VSIN18, TP_VSIN19, TP_VSIN20, TP_VSIN21, TP_VSIN22, TP_VSIN23: PTR1PAD1-13; P1-13
TP_VSS: PTR1PAD1-13; P1-13
U1: ADG714BRUZ; SOP65P640X120-24N
U$1: NANO

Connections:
CLK_OUT: CLOCK.5, DDS.5, DDS1.5, DDS2.5, DDS3.5, DDS4.5, DDS5.5, TP_MCLK.TP
COMP: C_DDS3.2, DDS.1
COMP1: C_DDS7.2, DDS1.1
COMP2: C_DDS11.2, DDS2.1
COMP3: C_DDS15.2, DDS3.1
COMP4: C_DDS19.2, DDS4.1
COMP5: C_DDS23.2, DDS5.1
DDS_SCLK: DDS.7, DDS1.7, DDS2.7, DDS3.7, DDS4.7, DDS5.7, R1.1, R2.2, TP_SCLK.TP
DDS_SCLK_5V: R1.2, U$1.D13
DDS_SDATA: DDS.6, DDS1.6, DDS2.6, DDS3.6, DDS4.6, DDS5.6, R3.1, R4.2, TP_SDATA.TP
FSYNC_CS1: DDS.8, R_PULLDOWN.2, TP_FSYNC.TP, U1.6
FSYNC_CS2: DDS1.8, R_PULLDOWN1.2, TP_FSYNC1.TP, U1.8
FSYNC_CS3: DDS2.8, R_PULLDOWN2.2, TP_FSYNC2.TP, U1.10
FSYNC_CS4: DDS3.8, R_PULLDOWN3.2, TP_FSYNC3.TP, U1.12
FSYNC_CS5: DDS4.8, R_PULLDOWN4.2, TP_FSYNC4.TP, U1.13
FSYNC_CS6: DDS5.8, R_PULLDOWN5.2, TP_FSYNC5.TP, U1.15
FSYNC_IN: R11.2, U1.5, U1.7, U1.9, U1.11, U1.14, U1.16, U1.18, U1.20
FSYNC_IN_5V: R11.1, U$1.D5
GND: CLOCK.2, CLOCK.4, C_CLK_BYP.2, C_DDS1.2, C_DDS2.2, C_DDS4.1, C_DDS5.2, C_DDS6.2, C_DDS8.1, C_DDS9.2, C_DDS10.2, C_DDS12.1, C_DDS13.2, C_DDS14.2, C_DDS16.1, C_DDS17.2, C_DDS18.2, C_DDS20.1, C_DDS21.2, C_DDS22.2, C_DDS24.1, C_OPA1.2, C_OPA2.2, C_OPA3.2, C_OPA4.2, C_OPA5.2, C_OPA6.2, C_OPA7.2, C_OPA8.2, C_OPA9.2, C_OPA10.2, C_OPA11.2, C_OPA12.2, C_OPB1.2, C_OPB2.2, C_OPB3.2, C_OPB4.2, C_OPB5.2, C_OPB6.2, C_OPB7.2, C_OPB8.2, C_OPB9.2, C_OPB10.2, C_OPB11.2, C_OPB12.2, C_OPC1.2, C_OPC2.2, C_OPC3.2, C_OPC4.2, C_OPC5.2, C_OPC6.2, C_OPC7.2, C_OPC8.2, C_OPC9.2, C_OPC10.2, C_OPC11.2, C_OPC12.2, C_OPD1.2, C_OPD2.2, C_OPD3.2, C_OPD4.2, C_OPD5.2, C_OPD6.2, C_OPD7.2, C_OPD8.2, C_OPD9.2, C_OPD10.2, C_OPD11.2, C_OPD12.2, DDS.4, DDS.9, DDS1.4, DDS1.9, DDS2.4, DDS2.9, DDS3.4, DDS3.9, DDS4.4, DDS4.9, DDS5.4, DDS5.9, LED_VDD.C, LED_VSS.C, R2.1, R4.1, R6.2, R8.2, R12.1, R13.1, R_DECOUP.2, R_DECOUP1.2, R_DECOUP2.2, R_DECOUP3.2, R_DECOUP4.2, R_DECOUP5.2, R_GAIN1.1, R_GAIN3.1, R_GAIN5.1, R_GAIN7.1, R_GAIN9.1, R_GAIN11.1, R_PULLDOWN.1, R_PULLDOWN1.1, R_PULLDOWN2.1, R_PULLDOWN3.1, R_PULLDOWN4.1, R_PULLDOWN5.1, R_S2D2.2, R_S2D6.2, R_S2D10.2, R_S2D14.2, R_S2D18.2, R_S2D22.2, S1.3, S2.1, TP_GND.TP, U1.4, U1.21, U$1.GND
unnamed: C_DDS4.2, DDS.3
unnamed: CLOCK.3, R_SET.2
unnamed: OP_GAIN.1, R_GAIN2.1, R_GAINF.3, R_S2D3.2, R_S2D4.2, TP_VSIN1.TP
unnamed: OP_S2D.6, OP_S2D.7, R_HOWA1.2, R_HOWB1.2, TP_VSIN3.TP
unnamed: OP_GAIN.2, R_GAIN1.2, R_GAIN2.2, R_GAINF.1
unnamed: OP_S2D.5, R_S2D4.1
unnamed: OP_HOWLA.5, R_HOWA1.1, R_HOWA3.1
unnamed: OP_S2D.1, R_HOWA2.2, R_HOWB2.2, R_S2D1.1, TP_VSIN2.TP
unnamed: OP_S2D.3, R_S2D2.1
unnamed: OP_S2D.2, R_S2D1.2, R_S2D3.1
unnamed: OP_HOWLB.3, R_HOWB2.1, R_HOWB3.1
unnamed: OP_HOWLB.2, R_HOWB1.1, R_HOWB5.1
unnamed: JP_OUT.2, R_HOWB3.2, R_HOWB4.1
unnamed: JP_OUT.1, R_HOWA3.2, R_HOWA5.2
unnamed: JP+.2, S1.2
unnamed: JP+.1, S1.4
unnamed: OP_HOWLA.7, R_HOWA4.1, R_HOWA5.1
unnamed: JP-.2, S2.2
unnamed: JP-.1, S2.4
unnamed: OP_HOWLA.6, R_HOWA2.1, R_HOWA4.2
unnamed: LED_VDD.A, R_VDD_LED.1
unnamed: LED_VSS.A, R_VSS_LED.1
unnamed: R3.2, U$1.D11
unnamed: OP_HOWLB.1, R_HOWB4.2, R_HOWB5.2
unnamed: C_DDS8.2, DDS1.3
unnamed: OP_GAIN1.1, R_GAIN4.1, R_GAINF1.3, R_S2D7.2, R_S2D8.2, TP_VSIN5.TP
unnamed: OP_GAIN1.2, R_GAIN3.2, R_GAIN4.2, R_GAINF1.1
unnamed: OP_S2D1.5, R_S2D8.1
unnamed: OP_S2D1.1, R_HOWA8.2, R_HOWB6.2, R_S2D5.1, TP_VSIN6.TP
unnamed: OP_S2D1.3, R_S2D6.1
unnamed: OP_S2D1.2, R_S2D5.2, R_S2D7.1
unnamed: OP_HOWLB1.2, R_HOWB7.1, R_HOWB9.1
unnamed: JP_OUT1.1, R_HOWA6.2, R_HOWA10.2
unnamed: OP_HOWLA1.7, R_HOWA9.1, R_HOWA10.1
unnamed: OP_HOWLA1.6, R_HOWA8.1, R_HOWA9.2
unnamed: OP_S2D1.6, OP_S2D1.7, R_HOWA7.2, R_HOWB7.2, TP_VSIN7.TP
unnamed: OP_HOWLB1.3, R_HOWB6.1, R_HOWB10.1
unnamed: OP_HOWLA1.5, R_HOWA6.1, R_HOWA7.1
unnamed: JP_OUT1.2, R_HOWB8.1, R_HOWB10.2
unnamed: OP_HOWLB1.1, R_HOWB8.2, R_HOWB9.2
unnamed: C_DDS12.2, DDS2.3
unnamed: OP_GAIN2.1, R_GAIN6.1, R_GAINF2.3, R_S2D11.2, R_S2D12.2, TP_VSIN9.TP
unnamed: OP_GAIN2.2, R_GAIN5.2, R_GAIN6.2, R_GAINF2.1
unnamed: OP_S2D2.5, R_S2D12.1
unnamed: OP_S2D2.1, R_HOWA13.2, R_HOWB11.2, R_S2D9.1, TP_VSIN10.TP
unnamed: OP_S2D2.3, R_S2D10.1
unnamed: OP_S2D2.2, R_S2D9.2, R_S2D11.1
unnamed: OP_HOWLB2.2, R_HOWB12.1, R_HOWB14.1
unnamed: JP_OUT2.1, R_HOWA11.2, R_HOWA15.2
unnamed: OP_HOWLA2.7, R_HOWA14.1, R_HOWA15.1
unnamed: OP_HOWLA2.6, R_HOWA13.1, R_HOWA14.2
unnamed: OP_S2D2.6, OP_S2D2.7, R_HOWA12.2, R_HOWB12.2, TP_VSIN11.TP
unnamed: OP_HOWLB2.3, R_HOWB11.1, R_HOWB15.1
unnamed: OP_HOWLA2.5, R_HOWA11.1, R_HOWA12.1
unnamed: JP_OUT2.2, R_HOWB13.1, R_HOWB15.2
unnamed: OP_HOWLB2.1, R_HOWB13.2, R_HOWB14.2
unnamed: C_DDS16.2, DDS3.3
unnamed: OP_GAIN3.1, R_GAIN8.1, R_GAINF3.3, R_S2D15.2, R_S2D16.2, TP_VSIN13.TP
unnamed: OP_GAIN3.2, R_GAIN7.2, R_GAIN8.2, R_GAINF3.1
unnamed: OP_S2D3.5, R_S2D16.1
unnamed: OP_S2D3.1, R_HOWA18.2, R_HOWB16.2, R_S2D13.1, TP_VSIN14.TP
unnamed: OP_S2D3.3, R_S2D14.1
unnamed: OP_S2D3.2, R_S2D13.2, R_S2D15.1
unnamed: OP_HOWLB3.2, R_HOWB17.1, R_HOWB19.1
unnamed: JP_OUT3.1, R_HOWA16.2, R_HOWA20.2
unnamed: OP_HOWLA3.7, R_HOWA19.1, R_HOWA20.1
unnamed: OP_HOWLA3.6, R_HOWA18.1, R_HOWA19.2
unnamed: OP_S2D3.6, OP_S2D3.7, R_HOWA17.2, R_HOWB17.2, TP_VSIN15.TP
unnamed: OP_HOWLB3.3, R_HOWB16.1, R_HOWB20.1
unnamed: OP_HOWLA3.5, R_HOWA16.1, R_HOWA17.1
unnamed: JP_OUT3.2, R_HOWB18.1, R_HOWB20.2
unnamed: OP_HOWLB3.1, R_HOWB18.2, R_HOWB19.2
unnamed: C_DDS20.2, DDS4.3
unnamed: OP_GAIN4.1, R_GAIN10.1, R_GAINF4.3, R_S2D19.2, R_S2D20.2, TP_VSIN17.TP
unnamed: OP_GAIN4.2, R_GAIN9.2, R_GAIN10.2, R_GAINF4.1
unnamed: OP_S2D4.5, R_S2D20.1
unnamed: OP_S2D4.1, R_HOWA23.2, R_HOWB21.2, R_S2D17.1, TP_VSIN18.TP
unnamed: OP_S2D4.3, R_S2D18.1
unnamed: OP_S2D4.2, R_S2D17.2, R_S2D19.1
unnamed: OP_HOWLB4.2, R_HOWB22.1, R_HOWB24.1
unnamed: JP_OUT4.1, R_HOWA21.2, R_HOWA25.2
unnamed: OP_HOWLA4.7, R_HOWA24.1, R_HOWA25.1
unnamed: OP_HOWLA4.6, R_HOWA23.1, R_HOWA24.2
unnamed: OP_S2D4.6, OP_S2D4.7, R_HOWA22.2, R_HOWB22.2, TP_VSIN19.TP
unnamed: OP_HOWLB4.3, R_HOWB21.1, R_HOWB25.1
unnamed: OP_HOWLA4.5, R_HOWA21.1, R_HOWA22.1
unnamed: JP_OUT4.2, R_HOWB23.1, R_HOWB25.2
unnamed: OP_HOWLB4.1, R_HOWB23.2, R_HOWB24.2
unnamed: C_DDS24.2, DDS5.3
unnamed: OP_GAIN5.1, R_GAIN12.1, R_GAINF5.3, R_S2D23.2, R_S2D24.2, TP_VSIN21.TP
unnamed: OP_GAIN5.2, R_GAIN11.2, R_GAIN12.2, R_GAINF5.1
unnamed: OP_S2D5.5, R_S2D24.1
unnamed: OP_S2D5.1, R_HOWA28.2, R_HOWB26.2, R_S2D21.1, TP_VSIN22.TP
unnamed: OP_S2D5.3, R_S2D22.1
unnamed: OP_S2D5.2, R_S2D21.2, R_S2D23.1
unnamed: OP_HOWLB5.2, R_HOWB27.1, R_HOWB29.1
unnamed: JP_OUT5.1, R_HOWA26.2, R_HOWA30.2
unnamed: OP_HOWLA5.7, R_HOWA29.1, R_HOWA30.1
unnamed: OP_HOWLA5.6, R_HOWA28.1, R_HOWA29.2
unnamed: OP_S2D5.6, OP_S2D5.7, R_HOWA27.2, R_HOWB27.2, TP_VSIN23.TP
unnamed: OP_HOWLB5.3, R_HOWB26.1, R_HOWB30.1
unnamed: OP_HOWLA5.5, R_HOWA26.1, R_HOWA27.1
unnamed: JP_OUT5.2, R_HOWB28.1, R_HOWB30.2
unnamed: OP_HOWLB5.1, R_HOWB28.2, R_HOWB29.2
SW_DIN: R7.2, R8.1, U1.3
SW_DIN_5V: R7.1, U$1.D4
SW_SCLK: R5.2, R6.1, U1.1
SW_SCLK_5V: R5.1, U$1.D9
SW_~RESET: R10.2, R13.2, U1.23
SW_~RESET_5V: R10.1, U$1.D3
SW_~SYNC: R9.2, R12.2, U1.24
SW_~SYNC_5V: R9.1, U$1.D2
VDD: CLOCK.1, C_CLK_BYP.1, C_DDS1.1, C_DDS2.1, C_DDS3.1, C_DDS5.1, C_DDS6.1, C_DDS7.1, C_DDS9.1, C_DDS10.1, C_DDS11.1, C_DDS13.1, C_DDS14.1, C_DDS15.1, C_DDS17.1, C_DDS18.1, C_DDS19.1, C_DDS21.1, C_DDS22.1, C_DDS23.1, C_OPA1.1, C_OPA3.1, C_OPA5.1, C_OPA7.1, C_OPA9.1, C_OPA11.1, C_OPB1.1, C_OPB3.1, C_OPB5.1, C_OPB7.1, C_OPB9.1, C_OPB11.1, C_OPC1.1, C_OPC3.1, C_OPC5.1, C_OPC7.1, C_OPC9.1, C_OPC11.1, C_OPD1.1, C_OPD3.1, C_OPD5.1, C_OPD7.1, C_OPD9.1, C_OPD11.1, DDS.2, DDS1.2, DDS2.2, DDS3.2, DDS4.2, DDS5.2, OP_GAIN.8, OP_GAIN1.8, OP_GAIN2.8, OP_GAIN3.8, OP_GAIN4.8, OP_GAIN5.8, OP_HOWLA.8, OP_HOWLA1.8, OP_HOWLA2.8, OP_HOWLA3.8, OP_HOWLA4.8, OP_HOWLA5.8, OP_HOWLB.8, OP_HOWLB1.8, OP_HOWLB2.8, OP_HOWLB3.8, OP_HOWLB4.8, OP_HOWLB5.8, OP_S2D.8, OP_S2D1.8, OP_S2D2.8, OP_S2D3.8, OP_S2D4.8, OP_S2D5.8, R_SET.1, R_VDD_LED.2, S1.1, TP_VDD.TP, U1.2
VOUT: C_DECOUP.1, DDS.10, TP_VSIN.TP
VOUT1: C_DECOUP1.1, DDS1.10, TP_VSIN4.TP
VOUT2: C_DECOUP2.1, DDS2.10, TP_VSIN8.TP
VOUT3: C_DECOUP3.1, DDS3.10, TP_VSIN12.TP
VOUT4: C_DECOUP4.1, DDS4.10, TP_VSIN16.TP
VOUT5: C_DECOUP5.1, DDS5.10, TP_VSIN20.TP
VSIN: C_DECOUP.2, OP_GAIN.3, R_DECOUP.1
VSIN1: C_DECOUP1.2, OP_GAIN1.3, R_DECOUP1.1
VSIN2: C_DECOUP2.2, OP_GAIN2.3, R_DECOUP2.1
VSIN3: C_DECOUP3.2, OP_GAIN3.3, R_DECOUP3.1
VSIN4: C_DECOUP4.2, OP_GAIN4.3, R_DECOUP4.1
VSIN5: C_DECOUP5.2, OP_GAIN5.3, R_DECOUP5.1
VSS: C_OPA2.1, C_OPA4.1, C_OPA6.1, C_OPA8.1, C_OPA10.1, C_OPA12.1, C_OPB2.1, C_OPB4.1, C_OPB6.1, C_OPB8.1, C_OPB10.1, C_OPB12.1, C_OPC2.1, C_OPC4.1, C_OPC6.1, C_OPC8.1, C_OPC10.1, C_OPC12.1, C_OPD2.1, C_OPD4.1, C_OPD6.1, C_OPD8.1, C_OPD10.1, C_OPD12.1, OP_GAIN.4, OP_GAIN1.4, OP_GAIN2.4, OP_GAIN3.4, OP_GAIN4.4, OP_GAIN5.4, OP_HOWLA.4, OP_HOWLA1.4, OP_HOWLA2.4, OP_HOWLA3.4, OP_HOWLA4.4, OP_HOWLA5.4, OP_HOWLB.4, OP_HOWLB1.4, OP_HOWLB2.4, OP_HOWLB3.4, OP_HOWLB4.4, OP_HOWLB5.4, OP_S2D.4, OP_S2D1.4, OP_S2D2.4, OP_S2D3.4, OP_S2D4.4, OP_S2D5.4, R_VSS_LED.2, S2.3, TP_VSS.TP

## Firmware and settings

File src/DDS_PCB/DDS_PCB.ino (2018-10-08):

// Library for handling the SPI transfer
#include <SPI.h>

#include "definitions.h"
#include "frequencies.h"
#include <stdio.h>

void setup() {

  Serial.begin(SERIAL_BAUD_RATE);

  pinMode(FSYNC1_Pin, OUTPUT);
  pinMode(FSYNC2_Pin, OUTPUT);
  pinMode(FSYNC3_Pin, OUTPUT);
  pinMode(FSYNC4_Pin, OUTPUT);
  pinMode(FSYNC5_Pin, OUTPUT);
  pinMode(FSYNC6_Pin, OUTPUT);

    //Set FSYNC pins High. FSYNC is active low
  digitalWrite(FSYNC1_Pin, HIGH); 
  digitalWrite(FSYNC2_Pin, HIGH); 
  digitalWrite(FSYNC3_Pin, HIGH);
  digitalWrite(FSYNC4_Pin, HIGH); 
  digitalWrite(FSYNC5_Pin, HIGH); 
  digitalWrite(FSYNC6_Pin, HIGH); 

  // For SPI data transfer setup
  pinMode(SDATA_SPI_Pin, OUTPUT);
  pinMode(SCLK_SPI_Pin, OUTPUT);

  digitalWrite(SDATA_SPI_Pin, LOW);
  digitalWrite(SCLK_SPI_Pin, LOW);

  // Arduino handles most of the underlying SPI transfer by itself, set it up here
  SPI.begin();  // Enable SPI
  SPI.setBitOrder(MSBFIRST);  // Send data Most significant bit first, this is necessary for the AD9833
  SPI.setDataMode(SPI_MODE2);  // Set SPI Mode 2 (Data captured on falling edge of clock, clock inversion on)
  SPI.setClockDivider(SPI_CLOCK_DIV128);    // Set clock divider (optional)
}

void loop() {

  byte byteRead; // Serial read data
  int val_to_program; // Frequency (Hz), phase (degrees), time etc.
  int chan_to_program;
  String what_to_program; //  Command to execute

  // Allow setting of frequency/phase from serial monitor
  // Input 'freq val_to_program' to program frequency
  // 'phase val_to_program' to set phase
    delay(ONE_SECOND_DELAY);
    if (PROGRAM_ALL) {
      Program_Freqs(Freqs, NUM_CHANNELS);
    }

    else {
      Program_One_Frequency(Freqs, CHANNEL_TO_PROGRAM);  
    }
    
  while (1) {
    // Wait for Serial data to be received and parse it


    
    if (Serial.available()) {

      what_to_program = Serial.readStringUntil(' '); // Get a string
      val_to_program = Serial.parseInt(); // Get an int
      chan_to_program = Serial.parseInt();

      // Process input and call appropriate commands
      // Can't use switch statement to do this as it won't accept a string as a comparator
      if (what_to_program == "reset")  {
        Reset_DDS(chan_to_program);
      }

      else if (what_to_program == "freq")     {
        Set_AD9833_Frequency(val_to_program, chan_to_program);
      }

      else if (what_to_program == "phase")	 {
        Set_AD9833_Phase(val_to_program, chan_to_program);
      }

      // default case - invalid command has been passed
      else {
        Serial.println("Command not recognised.");
      }
    }
  }
}


// Additional functions that may be helpful

void Program_Freqs (long Freqs [], int n_chans) {
  
  /* Loop through each freq/chan pair and program the switches/DDS chip */

  Serial.println("Programming default frequencies");
  for (int i = 0; i < n_chans; i++) {
    Serial.print("Programming channel ");
    Serial.println(i);
    Set_AD9833_Frequency(Freqs[i], i + 1);
  }
}

void Program_Then_Turn_Off(long freq, unsigned int on_time_milli, int chan) {

  /*Program the DDS chip for a given time, then turn off */

  //Program all of the channels, wait a specified time, then turn off.
  Set_AD9833_Frequency(freq, chan);
  delay(on_time_milli);
  Reset_DDS(chan);

}

void Program_One_Frequency(long Freqs [], int chan_to_turn_on) {
  /* Only program one current source, set all the rest to off/midscale DC output */

  Serial.print("Programming only source ");
  Serial.println(chan_to_turn_on);

  Reset_All();
  delay(100);
  Set_AD9833_Frequency(Freqs[chan_to_turn_on], chan_to_turn_on);    

}

void Sweep_Freq (int freq_min, int freq_step, int freq_max, int on_time, int chan) {
  /* Sweeps the frequency output on a channel, with increment and max value set by user.
freq_min: starting frequency (Hz)
freq_step: increment (Hz)
freq_max: Stopping frequency (Hz)
chan: which channel to program
on_time: how long to program each channel for (milliseconds) */

  for (int i = freq_min ; i <= freq_max; i = i + freq_step) {
    Set_AD9833_Frequency(i, chan);
    delay(on_time);
  }
}


void Reset_DDS(int chan) {
  /* Reset channel to midscale output (turns off AC output) */
  AD9833_SendWord(RESET_CONTROL_REGISTER, chan);
}


void Reset_All() {
  for (int i = 0; i < NUM_CHANNELS; i++) {
    Reset_DDS(i);
  }
 
}

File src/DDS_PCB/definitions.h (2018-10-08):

#ifndef definitions_h
#define definitions_h

// Arduino pin numberings
#define SDATA_SPI_Pin 11  // SDATA_SPI - Data signal for SPI, used to program AD9833
#define SCLK_SPI_Pin  13  // SCLK_SPI - Clock signal for SPI, used to program AD9833

// Parallel CS FSYNC Pins for Pro Mini
#define FSYNC1_Pin 2
#define FSYNC2_Pin 3
#define FSYNC3_Pin 4
#define FSYNC4_Pin 19
#define FSYNC5_Pin 20
#define FSYNC6_Pin 21

// Clock generator frequency, set by resistor R_SET on the PCB. This is used in the formula for setting the DDS sine wave frequency (Hz)
#define DDS_CLOCK_FREQUENCY 10e6

#define ONE_SECOND_DELAY 1000 //1000 milliseconds
#define SERIAL_BAUD_RATE 9600

#define PRINT_BUFFER_SIZE 50

#define SWITCH_DELAY_TIME 2    // Time to delay after programming switches
#define CONTROL_REGISTER_VALUE 0x2000    // Default value for control register of DDS chip
#define PHASE_REGISTER_VALUE 0xC000      // Default value for phase register of DDS chip
#define RESET_CONTROL_REGISTER 0x2100    // Reset control register of DDS to produce midscale output
#define PHASE_REGISTER_MAX 4096 // Maximum value of phase register
#define DDS_PROGRAM_CONSTANT 0x10000000 // 2^28
#define MAX_FREQUENCY 1e5 //Maximum frequency value, used for sanity check.

// Maximum value for injection when operating with limited length injections (milliseconds)
#define MAX_CAUTIOUS_INJECTION 25000

// Bit masks and shifts
#define LSB_BIT_MASK 0x3fff // Gives the 14 LSB of an unsigned long
#define SPI_BIT_MASK 0xFF // Gives 8 MSB of an unsigned int
#define FREQ_REG_MASK 0x4000 	//Use Register 0 (set 2 MSB to 01). To use Register 1, set 2MSB to 10 (0x8000)

#endif

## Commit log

2015-09-28 First commit of Tom's Parallel CS Prototype
    [BOM.xlsx, DRILEGEND.CFG, Parallel CS Prototype not linked to schematic.brd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]
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2015-09-29 Added ident layer to gerbers and finalised Pick and Place data
    [Parallel CS Prototype pick & place ident.brd, Pick & Place.xlsx]
2015-09-30 New Gerber files to include solder resist layer
    [Parallel CS Prototype not linked to schematic.brd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]
2015-10-07 Updated Pick & Place Data and Ident Gerber File for PCB assembly
    [Pick & Place.xlsx]
2015-10-16 Updating Arduino code to program new switch board
    [Pick & Place.xlsx]
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2015-11-12 Finalised design for 8 channel parallel CS, to be submitted to fabrication house.
    [Parallel CS Prototype multiple sources.brd, Parallel CS Prototype multiple sources.sch, Parallel CS Prototype not linked to schematic.brd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]
2015-11-24 Final Pick & Place Data, Ident Layers, for Assembly
    [Parallel CS Prototype V2 pick & place ident.brd]
2015-11-24 Merged development of 8 channel CS to master branch
    [DRILEGEND.CFG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]
2015-12-07 Arduino PWM code for generating sine waves
    [Pick & Place 60642 .xlsx]
2015-12-09 New 7mm x 8mm PCB to fix clock section of 8 channel parallel board.
    [Clock_circuit_fix.brd]
2016-07-07 Initial V4 design, single CS
    [Parallel CS V4.brd, Parallel CS V4.sch]
2016-07-12 V4 Design submitted for fab
    [Parallel CS V4.Multiple.Sources.brd, Parallel CS V4.brd]
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2016-07-19 Fixed resistor values in V4 PCB layout for HCP
    [Parallel CS V4.Multiple.Sources.brd]
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2016-12-06 Added function (Program_Then_Turn_Off) to program the sources for a specified amount of time, then turn them all off/reset
    [DDS_PCB.ino, Program_DDS.ino]
2016-12-16 Power supply connector board design
    [power_supply_board.brd, power_supply_board.sch, power_supply_board_repeated.brd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]
2016-12-20 V5 Parallel Board started
    [Parallel CS V5.brd, Parallel CS V5.sch]
2016-12-20 Changed power connecters, split output stage op amps into 2 separate ICs for medical safety regs
    [Parallel CS V5.brd, Parallel CS V5.sch]
2016-12-20 Changed FSYNC pull up resistor to pull down
    [Parallel CS V5.brd, Parallel CS V5.sch]
2016-12-21 Changes complete - PCB layout ready for tiling
    [Parallel CS V5.brd, Parallel CS V5.sch]
2016-12-21 Tiled board layout
    [Parallel CS V5 repeated.brd]
2017-01-23 V5.1 Board - fixing error with footprint of op-amp
    [Parallel CS V3.brd, Parallel CS V3.sch, Parallel CS V5 repeated.brd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]
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2017-03-20 More minor layout fixes
    [DDS_PCB.ino, Program_DDS.ino]
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2017-03-21 Replaced numeric constants in Program_DDS with defines
    [Program_DDS.ino, definitions.h]
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2017-03-21 Changed #include <iostream> to <stdio.h> to (hopefully) fix travis issue
    [DDS_PCB.ino, Program_DDS.ino]
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2017-03-21 Removed old schematics
    [BOM.xlsx, Clock_circuit_fix.brd, Parallel CS Prototype V2 pick & place ident.brd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]
2017-07-06 Started new connector board with high pass filter
    [Connector.Board.sch]
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2017-07-10 Added parts for 2 channels
    [Connector.Board.brd, Connector.Board.sch]
2017-07-10 example layout for 4 channels
    [Connector.Board.brd, Connector.Board.sch]
2017-07-10 now passing ERC
    [Connector.Board.brd, Connector.Board.sch]
2017-07-10 Duplicated layout through renaming parts
    [Connector.Board.brd, Connector.Board.sch]
2017-07-11 12 chn board finished
    [Connector.Board.brd, Connector.Board.sch]
2017-07-11 added drill holes and gerbers
    [Connector.Board.GBL, Connector.Board.GBO, Connector.Board.GBS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]
2017-07-13 version sent to PCBtrain. Simulations added also
    [Connector.Board.brd, Connector.Board.sch]
2017-07-17 AD9954 current source design. No ERC and DRC violations
    [Low.Noise.Current.Source.bkup.sch, Low.Noise.Current.Source.brd, Low.Noise.Current.Source.sch]
2017-07-17 Final layout tweaks done and Gerbers generated
    [Low.Noise.Current.Source.brd, Low.Noise.Current.Source.sch]
2017-07-18 Version before adding 32 channels
    [Connector.Board.brd, Connector.Board.sch]
2017-07-21 Renaming Sch and Brd but not matching yet
    [Connector.Board.brd, Connector.Board.sch]
2017-07-21 brd and sch match
    [Connector.Board.brd]
2017-07-24 Grounded input to test noise, this prevents 50Hz crosstalk when channel not in use
2017-07-24 switched bypass caps to 0402
    [Connector.Board.brd, Connector.Board.sch]
2017-07-24 Added Input resistor to ground. Started routing Dsub out
    [Connector.Board.brd, Connector.Board.sch]
2017-07-25 Finished dsub out and GND routing. Starting V planes
    [Connector.Board.brd]
2017-07-26 Finished PWR GND
    [Connector.Board.brd, Connector.Board.sch]
2017-07-26 Most of pins to AMPs routed
    [Connector.Board.brd]
2017-07-27 Schematic and PCB desig for AD9954 low noise current source
    [BOM.csv, Low.Noise.Current.Source.brd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]
2017-07-27 Finished Routing and First BOM
    [Connector.Board.GBL, Connector.Board.GBO, Connector.Board.GBS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]
2017-07-27 Finished Board
    [Connector.Board.brd, Connector.Board.sch]
2017-07-31 finished board with Gerbers and Info for PCBTrain
    [Connector.Board.GBL, Connector.Board.GBO, Connector.Board.GBS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]
2017-08-14 fixed BOM
    [ConnectorBoardPCB.xlsx]
2017-09-07 started case design
    [filter_board_case.SLDPRT]
2017-09-07 fixed wrong orientation on -ve led
    [Connector.Board.brd, Connector.Board.sch]
2017-09-08 Added case
    [Connector.Board.brd, Part2.SLDPRT, filter_board_case-Bottom.SLDPRT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]
2017-09-21 Fiddling with the case design
    [Connector.Board.brd, Connector.Board.sch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]
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2018-02-08 latest case and schematic for EEG board
    [Connector_Board_BOM.csv, filter_board_case-Bottom.SLDPRT, filter_board_case-Bottom.STL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]
2018-02-13 Added buffered ground
    [Connector.Board.brd, Connector.Board.sch]
2018-02-14 Added battery charger and Voltage inverter
    [Connector.Board.brd, Connector.Board.sch]
2018-02-15 Inital board layout for Voltage inverter and battery charger
    [Connector.Board.brd, Connector.Board.sch]
2018-02-15 bom for quote
    [ConnectorBoardPCB.xlsx]
2018-02-19 removed lib autosaved
    [Connector.Board.brd, Connector.Board.sch]
2018-02-19 final gerbers sent to PCBway
    [Connector.Board.GBL, Connector.Board.GBO, Connector.Board.GBS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]
2018-02-28 fixed error where inner layer gerbers werent updated

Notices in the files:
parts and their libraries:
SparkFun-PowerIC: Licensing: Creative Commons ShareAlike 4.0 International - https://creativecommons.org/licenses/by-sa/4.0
